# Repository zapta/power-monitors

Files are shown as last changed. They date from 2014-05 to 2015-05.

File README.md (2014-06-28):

POWER PLAY
==========

POWER PLAY are Arduino based smart power monitors that are used to measure and optimize the power consumption of battery operated devices such as smart phones. 

Following is a description of the POWER PLAY models.

POWER PLAY 3.8V
---------------
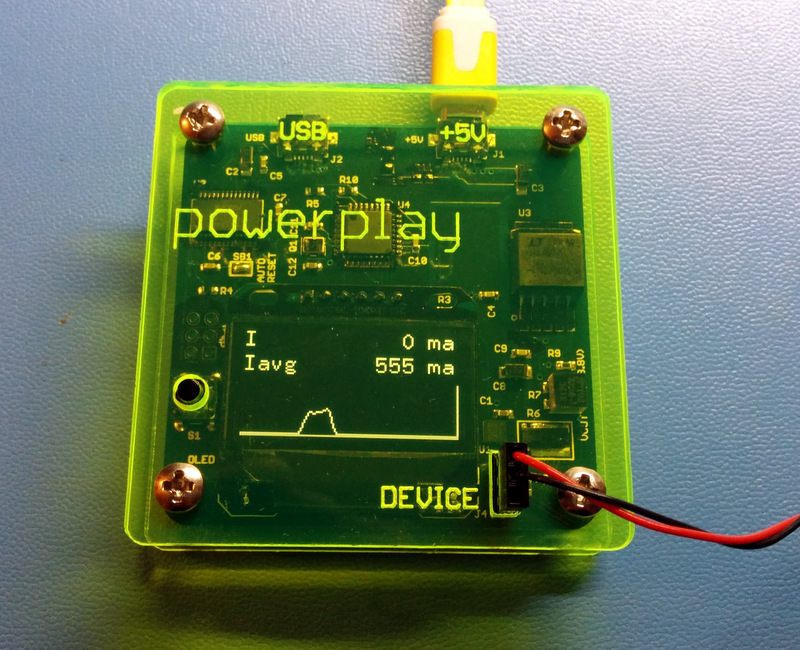
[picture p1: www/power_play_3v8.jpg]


This model provides the most accurate results but requires modifying the tested device. The POWER PLAY 3.8V outputs regulated 3.8 volts are simulates the power provided by a single cell Li-Ion battery cell. It requires disconnecting the battery from the tested device and hooking the output of the POWER PLAY 3.8V instead.

This model has 1.3" OLED display and on board analysis firmware such that it can be operated standalone. In addition is has a FTDI/USB output port that can be used to log the raw data on an attached computer and use it latter for additional analysis.

POWER PLAY 3.8V
---------------
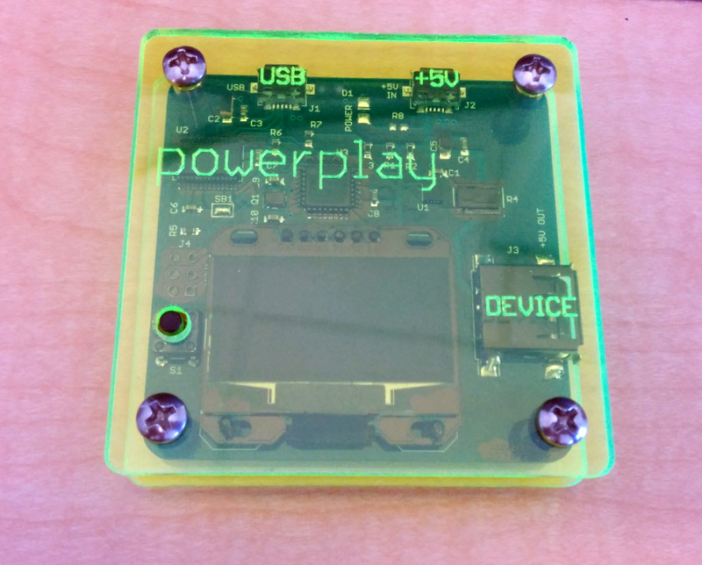
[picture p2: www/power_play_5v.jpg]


This model is identical to the POWER PLAY 3.8V except that it does not have the 3.8V regulator and instead it outputs a pass through 5V. It is intended to be used with unmodified test device by connecting the power to the charger input of the test device and measuring the current fluctuations after the internal battery is fully charged. This method provides less accurate results than the POWER PLAY 3.8V (with the battery removed) but is easier to use since it does not require modifying the test devices.

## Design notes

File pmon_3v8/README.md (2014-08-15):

POWER PLAY 3.8V
===============

## OVERVIEW
POWER PLAY 3V8 is an Arduino based measurement tool that is used to measure the power consumption of mobile devices under different conditions and software versions. It provides 3.8V 2A DC power that simulates a single cell Li-ion battery and is connected to the device **instead of the battery**. The POWER PLAY 3V8 analyzes the current pattern consumed by the device and provides aggregated data on an integral a 1.3" OLED display. It also output the data to a USB/Serial port so it can be logged by a computer for further analysis. The computer based logging is optional and in most cases not consumed since the POWER PLAY 3V8 provides the key results on the display in real time (e.g. the average current consumption over the measurement period).

**WARNING using the POWER PLAY 3.8V required modified devices with batteries removed. This modification should be done by qualified persons only due to the risk of fire, personal injury and even death. The POWER PLAY 3V8 information is provided here as-is and you must consult a qualified person before using it in any way. NEVER operate the POWER PLAY 3V8 with the battery connected to the device under test.**

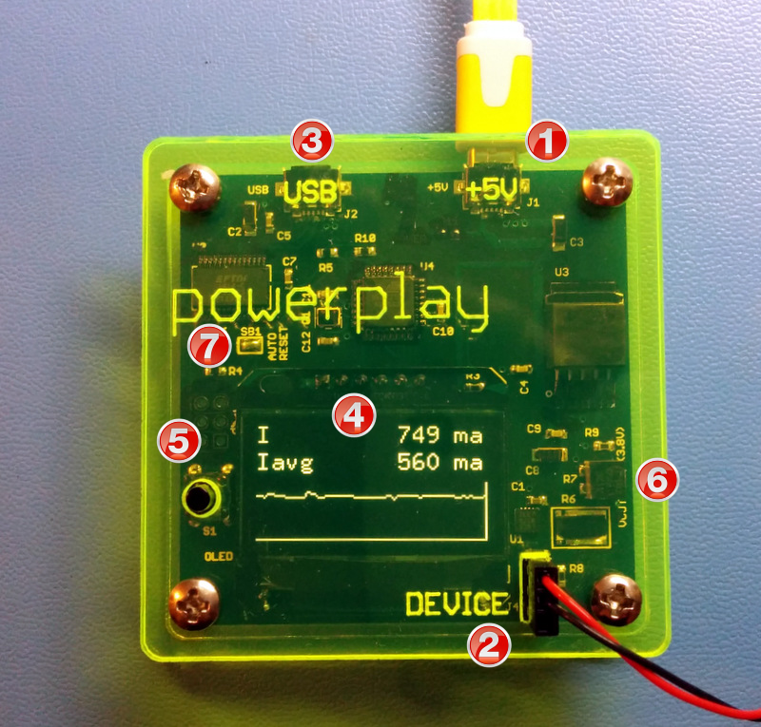
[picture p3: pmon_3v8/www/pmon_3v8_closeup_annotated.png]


1. +5V power input micro USB connector. This connector should be connected to a standard 5V charger and is used to power the POWER PLAY 3V8 and the device under test. It is important to use a charger that can provide sufficient current even during peak current consumption by the device under test. When testing a typical smart phone, powering the POWER PLAY 3V8 from a USB port or a small 1A charger typically result in insufficient current and unstable operation.

2. Power output connection to the device. This is a 3 pin standard servo connector (JR and Hitec style) with ground at the center pin and 3.8V DC (typical) at the two end pins (it's sufficient to use only one of them). This output voltage is adjustable (see below) and is connected to the device instead of the battery, emulating a single cell Lithium-ion battery.

3. USB connector. Using this connector is optional. It allows to log the raw data on an attached computer for later analysis. This connector implements a FTDI serial over USB port and can be access as a serial port on standard Mac OSX, Linux and Windows computers without additional drivers. The emulated serial port is 115.2kbs, 8 data bit, no parity and the data is in ASCII text format.

4. Display. This is a 1.3" monochrome OLED display that shows the analysis results. The display supports multiple pages with different data items.

5. Operation button. A short click switch the displayed data page and a long press (~4 seconds) resets the analysis variables and starts a new analysis session. Holding this button pressed while powering the POWER PLAY 3V8 activates the test screen (for post manufacturing tests).

6. This is a multi turn trim potentiometer that allows to adjust the output voltage in the range 3.6V - 4.2V. It is accessible from the side of the POWER PLAY 3V8 and requires a small flat screwdriver.

7. Auto Reset. This is a solder jumper on the PCB that controls the the USB auto reset feature. When shorted, establishing a new connection via the USB connector resets the POWER PLAY 3V8. This is useful when developing firmware for the POWER PLAY 3V8 using the Arduino IDE. If the auto reset is not desired (e.g. in order to have analysis sessions non interrupted by connecting the USB port), the short should be disconnected with a solder iron (after removing the 4 top screws and top cover).

TODO: add an overall picture with annotation for connectors, display, button and trim pot.

## FUNCTIONAL BLOCK DIAGRAM

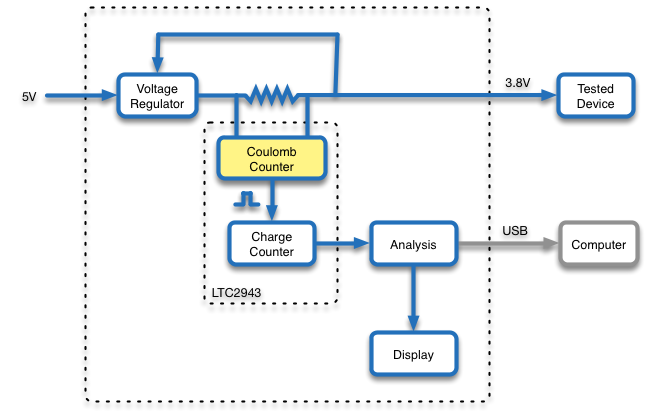
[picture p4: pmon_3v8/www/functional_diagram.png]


* **Voltage regulator** - a 5V to 3.8v low dropout (LDO) voltage regulator. The output voltage (nominal 3.8V) can be set by the small multi turn potentiometer on the right hand of the device.
* **Shunt resistor** - this is a small (25 milliohms) 1% Kelvin resistor that is used to sample the current consumed the the device. The voltage drop on the shunt does not affect the output voltage of the POWER PLAY 3V8 because of the feedback loop between the output voltage and the LDO.
* **Coulomb counter** - this is an analog circuit that continuously integrate the current through the shunt resistor and generates a pulse ('tick') whenever the charge since the last tick reaches a predefined value. (charge is the integral of current over time and is measured in Ampere Hours). For more information read the LTC2943 datasheet at http://www.linear.com/product/LTC2943.
* **Charge counter** - this is a digital counter that counts the Coulomb counter ticks. It provides the long term current integration.
* **Analysis** - this is firmware that tracks the current patterns and computes real time summary data such as momentary current, accumulated charge, number of times device transitioned from standby to wake mode and so on.
* **Display** - a small 1.3" OLED display that display the analysis results. The display has several pages, each with different data items, that can be switched using the button.
* **Computer** - this is an optional computer that logs the data over a USB connection. In most cases, the results displayed on the OLED displayed are sufficient and the computer is not necessary. 

## CONNECTION DIAGRAM

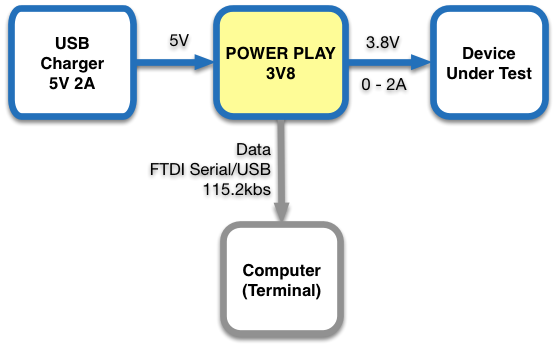
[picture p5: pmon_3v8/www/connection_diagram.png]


Plug the +5V micro usb connector to a USB charger with sufficient current (e.g. 2A). Plug the modified device to the DEVICE connector. Optional: to log the data on a computer connect the USB port to a computer and run a logging program or script (the POWER PLAY 3V8 looks like a 115.2kbs FTDI serial over USB port).

## ANALYSIS

The POWER PLAY 3V8 performs the analysis by dividing the time into slots of 100ms each (10Hz). For each time slot the analysis firmware samples the number of charge ticks occurred in that time slot (partial ticks are rolled to the next time slots, avoiding integration errors) and tracks the total ticks and time in global analysis counters. These counters are reset when the analysis is reset by long pressing the button. These values are used to compute, report and display the following values among others:

* Charge in last time slot.
* Average current during last time slot.
* Last time slot classification (I < ~80ma ? 'standby' : 'wake').
* Total analysis time.
* Total analysis charge (AmpHour).
* Average current during the analysis period.
* Total times of 'wake' and 'standby' slots.
* Total charge in 'wake' and 'standby' slots.
* Number of transitions from a 'standby' to 'wake' time slot.

The most important value from the above list is the average current during the analysis since it is inversely proportional to the expected battery life (for a given battery capacity).

Note: the analysis also samples and reports the momentary voltage level at each slot but in general it assumes that the voltage is fixed and thus does not track power (Watt) or energy (Watt Hour).

## OPERATION

Operating the POWER PLAY 3V8 is very simple. Connect the POWER PLAY 3V8 to a 5V 2A charger and the device under test as described above, reset the analysis by long pressing the button (~4 seconds) and let the device operate under the desired conditions. The analysis is done is real time and the results are shown on the display. Click the button to switch between display pages to see the desired values. 

IMPORTANT: the charger must be able to provide the peak current of the device under test. Make sure to have a brand name charger with sufficient power capabilities (e.g. 2A or larger). If the charger cannot provides the peak current, the device will turn off occasionally. 

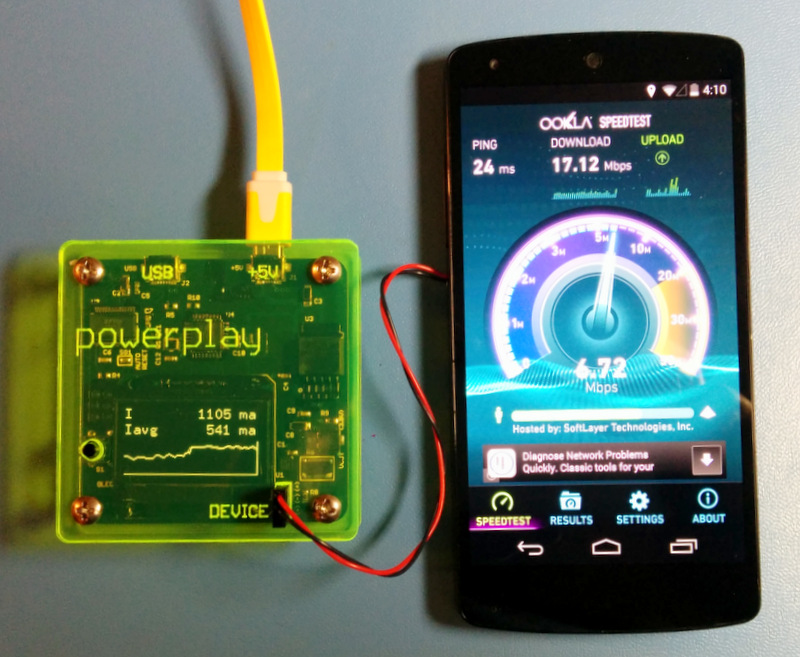
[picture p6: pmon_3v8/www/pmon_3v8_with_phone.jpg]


## LOG FORMAT
POWER PLAY output raw data for logging and offline analysis via the USB port. When connecting to a Linux, Mac OSC or Windows 
computer, the POWER PLAY appears as a serial port without having to install any special driver (it uses the default FTDI driver).
The serial port parameters are 115,200 bps, 8 data bit, no parity and it provides text based data (with CR/LF line ending)
with one record every 100 milliseconds. Each record contains the values listed below with a single space separator between
them.

```
8.200 0.131 0.000 0.163 0 8200 1 1
8.300 0.155 0.000 0.163 0 8300 1 1
8.400 0.131 0.000 0.163 0 8400 1 1
8.500 0.042 0.000 0.161 100 8400 1 0
8.600 0.018 0.000 0.159 200 8400 1 0
8.700 0.018 0.000 0.158 300 8400 1 0
8.800 0.012 0.000 0.156 400 8400 1 0
8.900 0.018 0.000 0.155 500 8400 1 0
9.000 0.030 0.000 0.153 600 8400 1 0
9.100 0.060 0.000 0.152 600 8500 2 1
9.200 0.042 0.000 0.151 700 8500 2 0
```

The fields of each log line are as follows

* **T** - Timestamp since the beginning of the analysis (long press the button) in milliseconds.
* **I** - Average current during the last 100ms time slot, in Amperes.
* **Q** - Total charge since the beginning of the analysis in Ampere/Hours.
* **Iavg** - Average current since the beginning of the analysis in millliamps.
* **Ts** - Total time since the beginning of the analysis of 100ms time slot that were classified as 'standby' (average current was lower than a predefined threshold.
* **Tw** - Total time since the beginning of the analysis of 100ms time slot that were classified as 'wake' (average current was higher than a predefined threshold. (this field is redundant since it is always equals T - Ts).
* **Nw** - number of transitions from a 'standby' (100ms) time slot to a 'wake' time slot. 
* **W** - a boolean flag that indicates if the last 100ms time slot was classified as 'wake' (value = 1) or as 'standby' (value = 0).

## INSTRUMENTING A DEVICE
The process of instrumenting a mobile device to be used with POWER PLAY 3.8V varies for each device and should be done only by qualified personal that understand the device and the hazards of dealing with rechargeable Li-Ion batteries (risk or fire, personal injury and death so **beware**). For that reason, it is in out of the scope of this document.

Following are the steps used to instrument one specific phone model (Nexus 5) that was used to test the POWER PLAY 3.8V. This is provided as general information only and not as a comprehensive guide. The procedure for other devices can be very different, some may require additional capacitors in parallel to the two wires, other can require special 'fake' batteries while others can be completely incompatible with POWER PLAY 3.8V.

1. Open the back cover (pry around)
2. Remove the black plastic cover above the battery (require removal of 6 small screws).
3. Carefully disconnect the battery connector and the large flex connector next to it.
4. Remove the battery (you need to pry below it, be careful not to damage the battery).
5. Place back the large flex cable.
6. Solder two wires to the points shown the in the picture below.
7. Put back the black cover and secure with the 6 screws.
8. Cut a small notch at the edge of the back cover to have clearance for the two wires.
9. Put back the black cover.
10. Solder the two wires to a 3 position HiTech/JR (but not Futaba) servo connector. Connect the center position to the (-) wires and one of the end positions to the (+) wire.

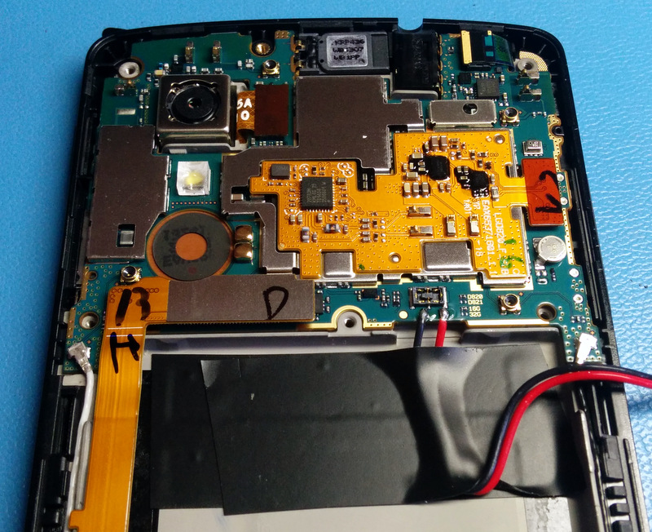
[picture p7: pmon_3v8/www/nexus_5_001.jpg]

The Nexus 5 with cover and battery removed and two wires soldered.

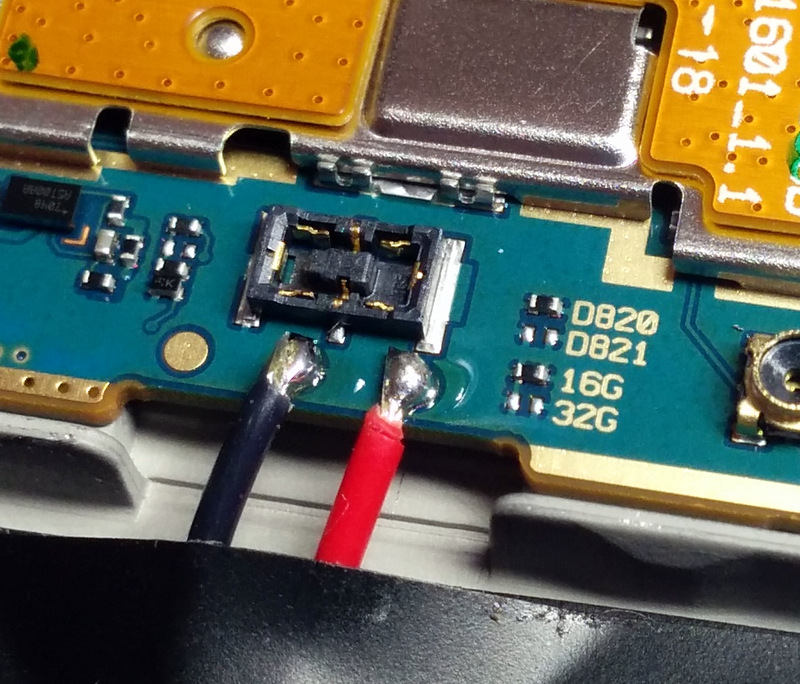
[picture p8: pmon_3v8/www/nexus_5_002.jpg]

A close up of the two connection points.

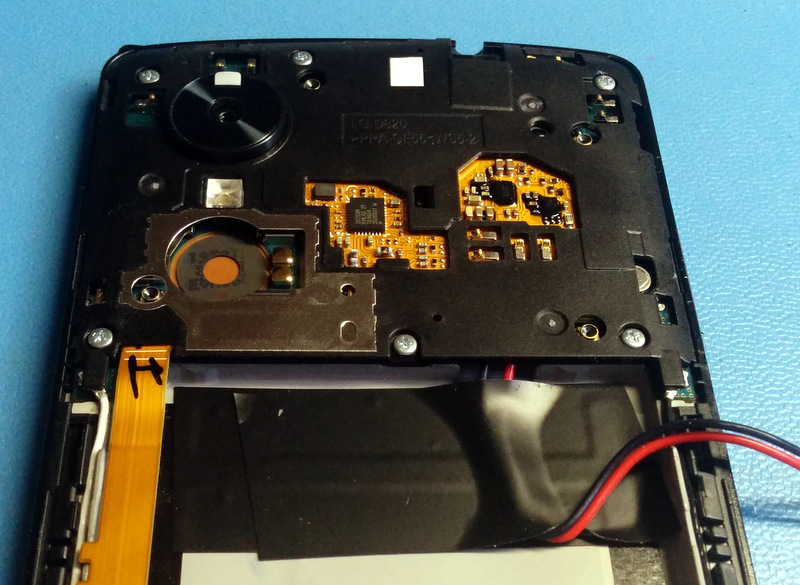
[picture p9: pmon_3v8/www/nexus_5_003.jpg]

The phone with the black cover back in place and the wires secured with tape.

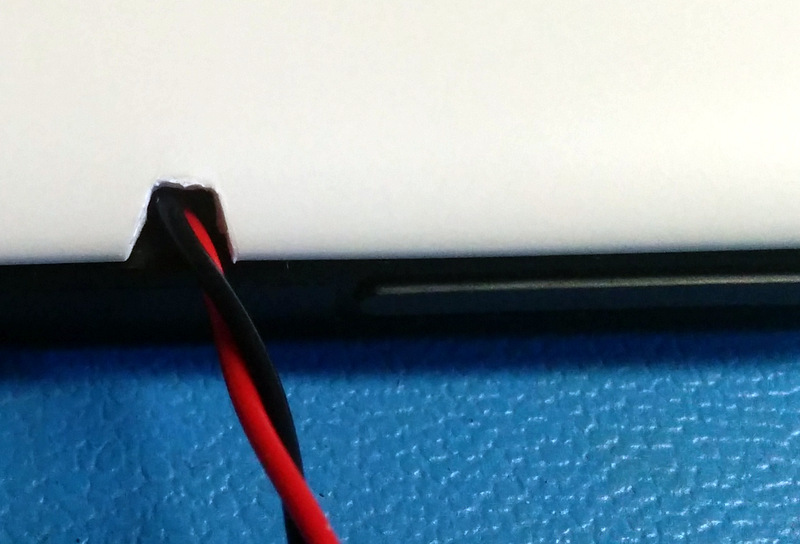
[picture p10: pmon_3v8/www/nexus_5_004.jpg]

The exit point of the two wires.

## FIRMWARE DEVELOPMENT

POWER PLAY 3.8V is compatible with the Arduino IDE and its firmware is an Arduino sketch whose source code is available in this directory. Here are a few notes that will help you setup the development environment.

* You need to power the POWER PLAY 3.8V via its +5V connector in addition to connecting the USB port to the host computer with the Arduino IDE.
* The POWER PLAY 3.8V looks to the Arduino IDE as an Arduino Pro Mini 16Mhz 5V ATMEGA328 board. You need to select it in the Tool section of the IDE menu.
* You can use the IDE serial monitor facility to view output from the POWER PLAY 3.8V.
* The POWER PLAY 3.8V sketch uses the U8glib graphic library. You need to install it on your Arduino IDE before being to compile the POWER PLAY 3.8V sketch. To do so, follow the 'manual instructions' here https://code.google.com/p/u8glib/wiki/u8glib (using the IDE's library import function results in compilation errors).

## BUILDING POWER PLAY 3V8

Follow these steps to build your own POWER PLAY: 

* Purchase the electronic components listed in the Bill Of Material (BOM) file. Most components are available from common sources such as digikey.com. You can purchase the OLED display directly from heltec.cn or from retailers such as eBay sellers. Make sure to purchase a white SPI display with 6 pins that match the pins in the schema (these display use the SSD1306 controller).
* Order the printed circuit board (PCB). It is a 2 layers PCB with a Sick of Beige 60mm x 60mm form factor. Some vendors such as OSHPark.com accept Eagle .brd files directly. Others such as elecrow.com require you to generate gerber files using their custom Eagle .cam files.
* Order a SMD stencil (5mil or 0.125mm) for the PCB. For best results, use a metal stencil (e.g. from elecrow.com) rather than mylar.
(optional) Make the top and bottom laser cut covers. We got the best results with acrylic 1/8” fluoro blue or green. If you do not have access to a laser cutter, you can order online from services such as ponoko.com. 
* Print, pick-and-place and reflow the SMD components, including the two micro USB connectors (use solder paste, the stencil and the reflow method of your choice such as hot air station, hot plate or a toaster oven).
* Solder the through-hole components (two 1 pin OLED support posts, OLED display, push button, and 3 pin output header). Connecting the solder jumper SB1 is optional but recommended.
* Power the board via the +5V connector and use an ICSP programmer of your choice (e.g. Atmel ICSP MKII with pogo pins) to program the MCU  (see the script file icsp_program_all.sh for an example). Alternatively, you can program the MCU before soldering, using a universal programmer. This step programs the MCU fuses, the MCU Arduino bootloader, and the POWER PLAY firmware. 
* (optional) Assemble the top and bottom covers using the screws and spacers listed in the BOM. If not using the covers, you can use screws and nuts to have the PCB standing on 4 legs.

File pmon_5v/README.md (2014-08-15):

POWER PLAY 5V
=============

## OVERVIEW
POWER PLAY 5V is identical to the POWER PLAY 3.8V except that it passes through the input 5V instead of down regulating it to 3.8V. This allows to use unmodified test devices (that is, no need to remove the battery) and the cost of slightly less accurate results do the quiescent current of the internal charger circuitry of the test devices and potential difference is software behavior due to the detection of the charger power. 

Since many aspects of POWER PLAY 5V are identical to POWER PLAY 3.8V, we list here only the differences.

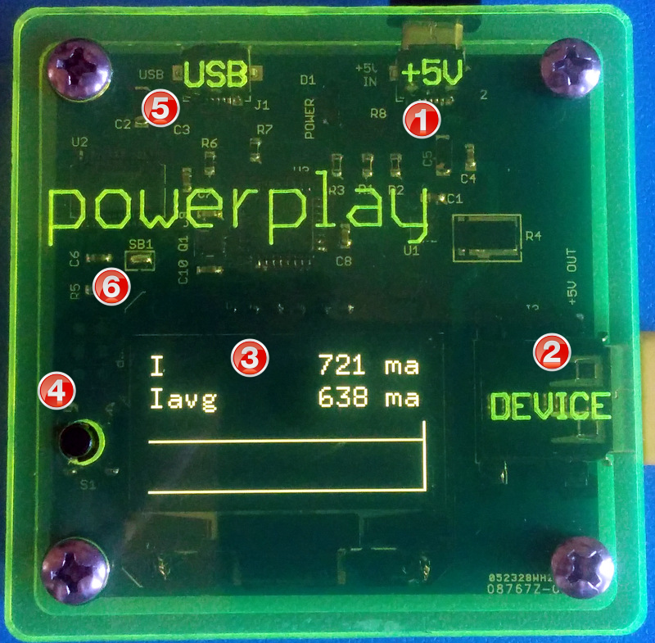
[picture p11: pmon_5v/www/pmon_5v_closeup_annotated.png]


1. +5V power input micro USB connector. Identical to POWER PLAY 3.8V.

2. Power output connection to the device. Connect this using a short USB cable to the test device.

3. Display. Identical to POWER PLAY 3.8V.

4. Operation button. Identical to POWER PLAY 3.8V.

5. USB connector. Identical to POWER PLAY 3.8V.

6. Auto Reset solder jumper. Identical to POWER PLAY 3.8V.

## FUNCTIONAL BLOCK DIAGRAM

Identical to POWER PLAY 3.8V except that a pass through wire replaces the 3.8V regulator.

## CONNECTION DIAGRAM

Identical to POWER PLAY 3.8V except that the test device is powered via its USB charger port.

## ANALYSIS

Identical to POWER PLAY 3.8V.

## OPERATION

1. Connect the +5V connector to 2A or larger charger.
2. Connect the DEVICE connector to the charger port of the test device (e.g. Nexus 5).
3. Wait until the device is *fully* charged.
4. Long press the button to reset the analysis and let POWER PLAY monitor the current for some time.
5. Note the Iavg value. This is the baseline current consumption of your device.
6. Install the new app and repeat steps 4, 5. The difference in Iavg values with and without the app indicates the power consumption of the app (lower is better).
7. Optimize the app and repeat. Your users will love you for better battery life.

## LOG FORMAT

Identical to POWER PLAY 3.8V.

## INSTRUMENTING A DEVICE

Not required.

## FIRMWARE DEVELOPMENT

Identical to POWER PLAY 3.8V.

## BUILDING POWER PLAY 5V. 

Similar to POWER PLAY 3.8V.

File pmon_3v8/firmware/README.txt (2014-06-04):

Arduino PMon OLED board programming.

Use AVR ICSP programmer such as AVR ISP MKII and programming software
such as AVRDUDE or AVRDUDES. Many other programmers and programming
software will also work.

Use the 2x3 ICSP programming header on the Pmon OLED board. Make sure you
orient it correctly (connect from the top side, pay attention to pin 1).
You can solder header pins or use pogo pins like Sparkfun's 
ISP Pogo Adapter. Other adapters like Hobbyking's Atmega Socket Firmware 
Flashing Tool may also work.

MCU type: ATmeta328P

Fuses:
L  : 0xFF
H  : 0xDA
E  : 0x05
LB : 0x3F

Flash image: pmon_oled_flash.hex

The image includes an Arduino Mini Pro bootloader so once
programmed, you can program software changes directly from
the Arduino IDE (board = Arduino Pro Mini 5V 16Mhz) via the 
USB port.

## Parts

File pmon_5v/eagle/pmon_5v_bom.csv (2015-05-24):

Quantity | Digi-Key Part Number | Description | Package | Manufacturer Name | Manufacturer Part Number | Part Numbers | Comments
1 | FC4L64R025FERCT-ND | 0.025 ohm 1% 2W Kelvin | SMT 2512 | Ohmite | FC4L64R025FER | R4
4 | 311-3.30KHRCT-ND | 3.3K 5% 1/10W | SMT 0603 | Yageo | RC0603FR-073K3L | R1 R2 R3 R8 | Generic part
3 | 311-10KGRCT-ND | 10k 5% 1/10W | SMT 0603 | Yageo | RC0603JR-0710KL | R5 R6 R7 | Generic part
2 | 311-1424-1-ND | 20pF 50V 5% | SMT 0603 | Yageo | CC0603JRNPO9BN200 | C9 C10 | Generic part
5 | 311-1344-1-ND | 0.1uf 10% 25V | SMT 0603 | Yageo | CC0603KRX7R9BB104 | C3 C5 C6 C7 C8 | Generic part. May need to reduce C7 if interferes with ICSP reset (e.g. to 0.01)
3 | 445-1604-1-ND | 1uF 16V 5% | SMT 6030 | TDK Corporation | C1608X7R1C105K080AC | C1 C11 C12 | Generic part
2 | 399-3684-1-ND | 10uF 10% 16V | SMT 1206 | Kemet | T491A106K010AT | C2 C4 | Generic part
1 | CTX732CT-ND | 16Mhz Crystal 20pf | 4-SMD 3.20mm x 2.50mm | CTS-Frequency Control | 403C11E16M00000 | Q1 | CTS 403 Series 20pF.
1 | ATMEGA328P-AURCT-ND | ATMEGA328P | TQFP32 | Atmel | ATMEGA328P-AUR | U3 | Atmel AVR328P
1 | 768-1007-1-ND | FT232RL | SSOP28 | FTDI | FT232RL-REEL | U2
1 | LTC2943CDD#PBF-ND | LTC2943 | DFN8 | Liner Technology | LTC2943CDD#PBF | U1 | Adjustable LDO 3A.
1 | TC10154.0VCT713CT-ND | TC1015 | SOT23-5 | Microchip Technology | TC1015-4.0VCT713 | U4 | Fixed LDO 4.0V.
1 | P12197S-ND | Push button |  | Panasonic Electronic Components | EVQ-PAG09K | S1 | Panasonic EVQ-PAG09K
2 | S1011E-36-ND | 1 position 0.1" straight |  | Sullins Connector Solutions | PBC36SAAN | OLED mechanical support. | Generic part. Height above board should be at most 8.5mm. The part number here is for a 36 position breakable strip so it can be used for multiple boards.
2 | H11611CT-ND | Micro USB 'reversed' connector |  | Hirose Electric Co Ltd | ZX62RD-AB-5P8 | J1 J2 | Hirose ZX62RD-AB-5P8. Make sure it is a 'reversed' connector otherwise the signals will be in reversed order.
1 | WM7087TR-ND | USB A connector |  | Molex Inc | 482580002 | J3 | Molex 48258-0002
4 | 335-1156-ND | M3x6mm pan head philips machine screw |  | APM Hexseal | RM3X6MM 2701 |  | Top cover screws
4 | 335-1148-ND | M3x10mm pan head philips machine screw |  | APM Hexseal | RM3X10MM 2701 |  | Bottom cover screws
4 | 952-1515-ND | M3x6mm round threaded female/female metal standoff |  | Harwin | R30-5000602 |  | Top cover standoff
4 | 952-1526-ND | M3x3mm round non threaded nylon or metal spacer |  | Harwin | R30-6700394 |  | Bottom cover spacer
1 | N/A | Heltec 1.3" SPI 128X64 OLED WHITE monochrome display with RST pin. |  | Heltec |  | OLED | Must have SSD1306 controller and these 6 pins: GND VCC SCL SDA RST D/C (picture here http://i.imgur.com/y3cWazS.jpg). Manufacturer is http://www.heltec.cn. Heltec also similar blue models (with sh1063 controller) and 'new' models with different 6 pins (VCC and GND swapped no RST pin) these two models are incompatible with the current POWER PLAY design.
1 | N/A | PCB |  |  |  |  | Order the PCB from your favorite PCB manufacturer (2 layers 60x60mm). Make sure to order a SMD stencil preferably 5mil stainless steal but even a 5 mil stencil from oshstencils.com should work.
1 | N/A | Top cover |  |  |  |  | Laser cut fluorescent green 1/8" acryilic.
1 | N/A | Bottom Cover |  |  |  |  | Laser cut fluorescent green 1/8" acryilic.

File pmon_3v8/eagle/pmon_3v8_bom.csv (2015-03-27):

Quantity | Description | Part Designators | Digikey Part Number | Comments
1 | 0.025 ohm 1% Kelvin | R6 | FC4L64R025FERCT-ND | Ohmite FC4L64R025FER
5 | 3.3K 1% 1/10W 0603 | R1 R2 R3 R9 R11 | P3.30KHCT-ND
1 | 8.2K 1% 1/10W 0603 | R8 | P8.20KHCT-ND
3 | 10k 5% 1/10W 0603 | R4 R5 R10 | 311-10KGRCT-ND
1 | 1K 12 turns side adjustment | R7 | 3224J-102ECT-ND | Bourns 3224J-1-102E
2 | 20pF 50V 5% 0603 | C11 C12 | 311-1424-1-ND
6 | 0.1uf 10% 25V 0603 | C4 C5 C6 C7 C9 C10 | 311-1344-1-ND | Reduce C7 if interferes with ICSP reset (e.g. to 0.01)
3 | Ceramic cap 1uF 16V 5% 0603 | C1 C13 C14 | 445-1604-1-ND
3 | Tantalum cap 10uF 10% 16V 1206 | C2 C3 C8 | 399-3684-1-ND
1 | Heltec 1.3" SPI 128X64 OLED WHITE monochrome display with RST pin. | OLED |  | http://www.heltec.diytrade.com or http://r.ebay.com/bVQ2CYMust have SSD1306 controller and these 6 pins: GND VCC SCL SDA RST D/C (picture here http://i.imgur.com/y3cWazS.jpg). Manufacturer is http://www.heltec.cn. Heltec also similar blue models (with sh1063 controller) and 'new' models with different 6 pins (VCC and GND swapped no RST pin) these two models are incompatible with the current POWER PLAY design.
1 | 16Mhz crystal | Q1 | CTX732CT-ND | CTS 403 Series 20pF.
1 | ATMEGA328P TQFP32 | U4 | ATMEGA328P-AURCT-ND | Atmel AVR328P
1 | FT232RL SSOP28 | U2 | 768-1007-1-ND
1 | LTC2943 DFN8 | U1 | LTC2943CDD#PBF-ND
1 | LT1764AEQ TO263 | U3 | LT1764AEQ#TRPBFCT-ND | Adjustable LDO 3A.
1 | TC1015 SOT23-5 | U5 | TC10154.0VCT713CT-ND | Fixed LDO 4.0V.
1 | Push button | S1 | P12197S-ND | Panasonic EVQ-PAG09K
1 | 3 positions 0.1" header straight | J4 | S1011E-36-ND | Generic part. Height above board should be at most 8.5mm. The part number here is for a 36 position breakable strip so it can be used for multiple boards.
2 | 1 position 0.1" header straight | OLED mechanical support. | S1011E-36-ND | Generic part. Height above board should be at most 8.5mm. The part number here is for a 36 position breakable strip so it can be used for multiple boards.
1 | RC Hitech/JR servo 3 positions male connector + 2 pins | Mates with J3 |  | Any RC store or ebay. The top cover laser cut was design for JR/Hitech housings not Futaba.
2 | Micro USB 'reversed' connector | J1 J2 | H11611CT-ND | Hirose ZX62RD-AB-5P8. Make sure it is a 'reversed' connector otherwise the signals will be in reversed order.
1 | PCB |  |  | Order the PCB from your favorite PCB manufacturer (2 layers 60x60mm). Make sure to order a SMD stencil preferably 5mil stainless steal but even a 5 mil stencil from oshstencils.com should work.
1 | Top cover custom acrylic |  |  | Laser cut fluorescent green 1/8" acryilic.
1 | Bottom cover custom acrylic |  |  | Laser cut fluorescent green 1/8" acryilic.
4 | M3x6mm pan head philips machine screw |  | 335-1156-ND | Top cover screws
4 | M3x10mm pan head philips machine screw |  | 335-1148-ND | Bottom cover screws
4 | M3x6mm round threaded female/female metal standoff |  | 952-1515-ND | Top cover standoff
4 | M3x3mm round non threaded nylon or metal spacer |  | 952-1526-ND | Bottom cover spacer

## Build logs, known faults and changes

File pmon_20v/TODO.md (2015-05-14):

TODO list for The Arduino PMON UNO

**SCHEMATIC**
* Add solder jumpers for OLED soft configuration.

**LAYOUT**
* Add to the OLED footprint a tplace rectangle with the active display area.
* Add to the OLED footprint a restrict/keepout for the area below the passive components.

** Enclosure

**SOFTWARE**

**MISCELLANEOUS**
* Add README.md file

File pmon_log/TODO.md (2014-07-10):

TODO list for The Arduino PMON UNO

**SCHEMATIC**

**LAYOUT**

** Enclosure

**SOFTWARE**

**MISCELLANEOUS**

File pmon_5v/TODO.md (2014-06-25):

TODO list for The Arduino PMON UNO

**SCHEMATIC**
* Add solder jumpers for OLED soft configuration.
* Add a 10K resistor from OLED RST to ground to have smoother startup.

**LAYOUT**
* Add to the OLED footprint a tplace rectangle with the active display area.
* Add to the OLED footprint a restrict/keepout for the area below the passive components.
* Add BOM

** Enclosure

**SOFTWARE**
* Show time as [[hh:]mm:]ss.

**MISCELLANEOUS**

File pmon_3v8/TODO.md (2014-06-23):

TODO list for POWER PLAY 3V8

**SCHEMATIC**
* Find part number of a button without the fifth ground pin.
* Add config pin for new OLED configuraiton.

**LAYOUT**
* Add to the OLED footprint a tplace rectangle with the active display area.
* Add to the OLED footprint a restrict/keepout for the area below the passive components.
* Add to top silkscreen layer display dignal names.

** Enclosure

**SOFTWARE**
* Make sure zero current is mapped in the graph to bottom display row.

**MISCELLANEOUS**

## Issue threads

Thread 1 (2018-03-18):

error when upload

lutfisan, 2018-03-18:
I use arduino nano,
when I verify the code it is ok, but when I upload it I get error

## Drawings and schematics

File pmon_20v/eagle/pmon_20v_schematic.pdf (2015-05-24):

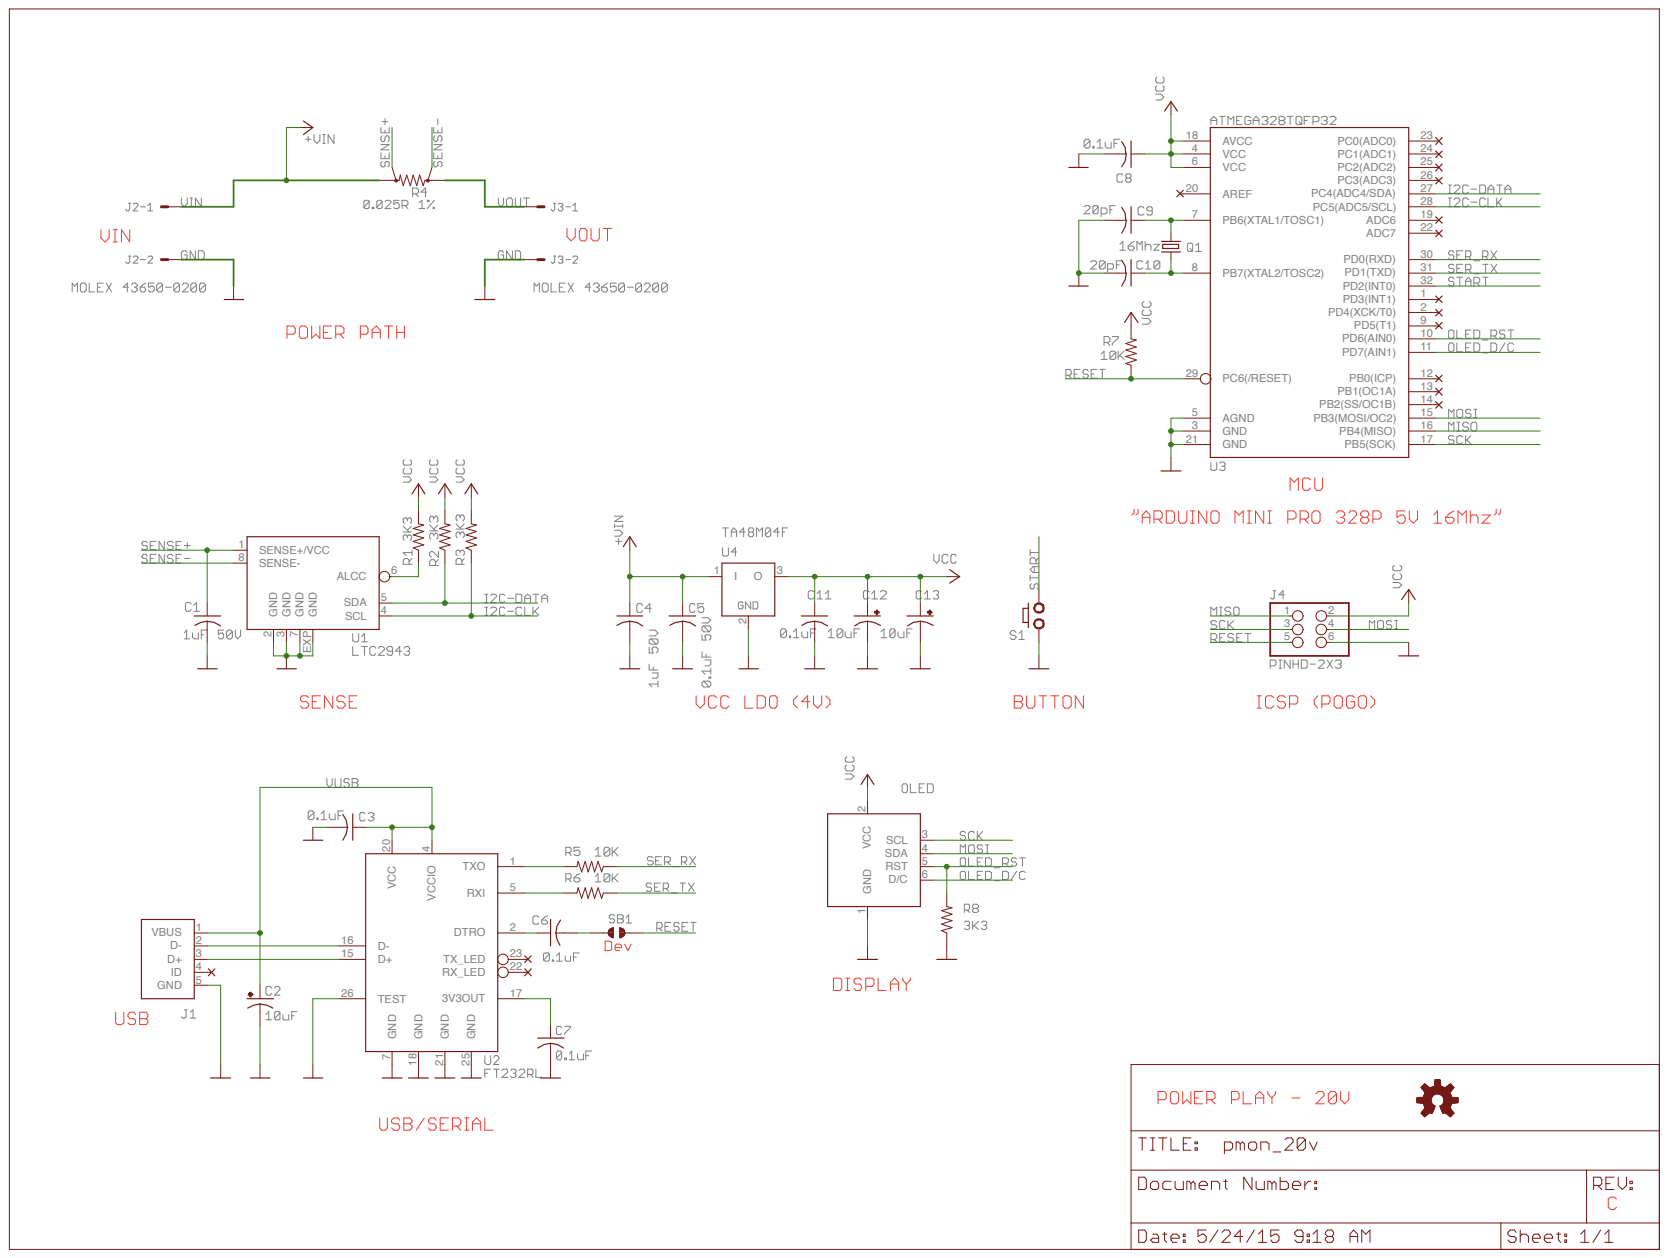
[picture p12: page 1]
ALCC; GND 2; GND 3; GND 7; GND EXP; SCL; 4 SDA; SENSE+/VCC; SENSE-; GND; VBUS; ADC6; ADC7; AGND; AREF 20; AVCC 18; 3 GND 21; PB0(ICP); PB3(MOSI/OC2); PB4(MISO); PB5(SCK); PB6(XTAL1/TOSC1); PB7(XTAL2/TOSC2); PC0(ADC0); PC1(ADC1); PC2(ADC2); PC3(ADC3); PC4(ADC4/SDA); PC5(ADC5/SCL); PC6(/RESET) 29; PD0(RXD); PD1(TXD); PD2(INT0); PD3(INT1); PD4(XCK/T0); PD6(AIN0); PD7(AIN1); VCC; 3V3OUT; DTRO; GND 18; GND 21; GND 25 RXI; RX_LED; TEST 26; TXO; TX_LED; VCC 20; VCCIO 4; GND 1; RST; SDA

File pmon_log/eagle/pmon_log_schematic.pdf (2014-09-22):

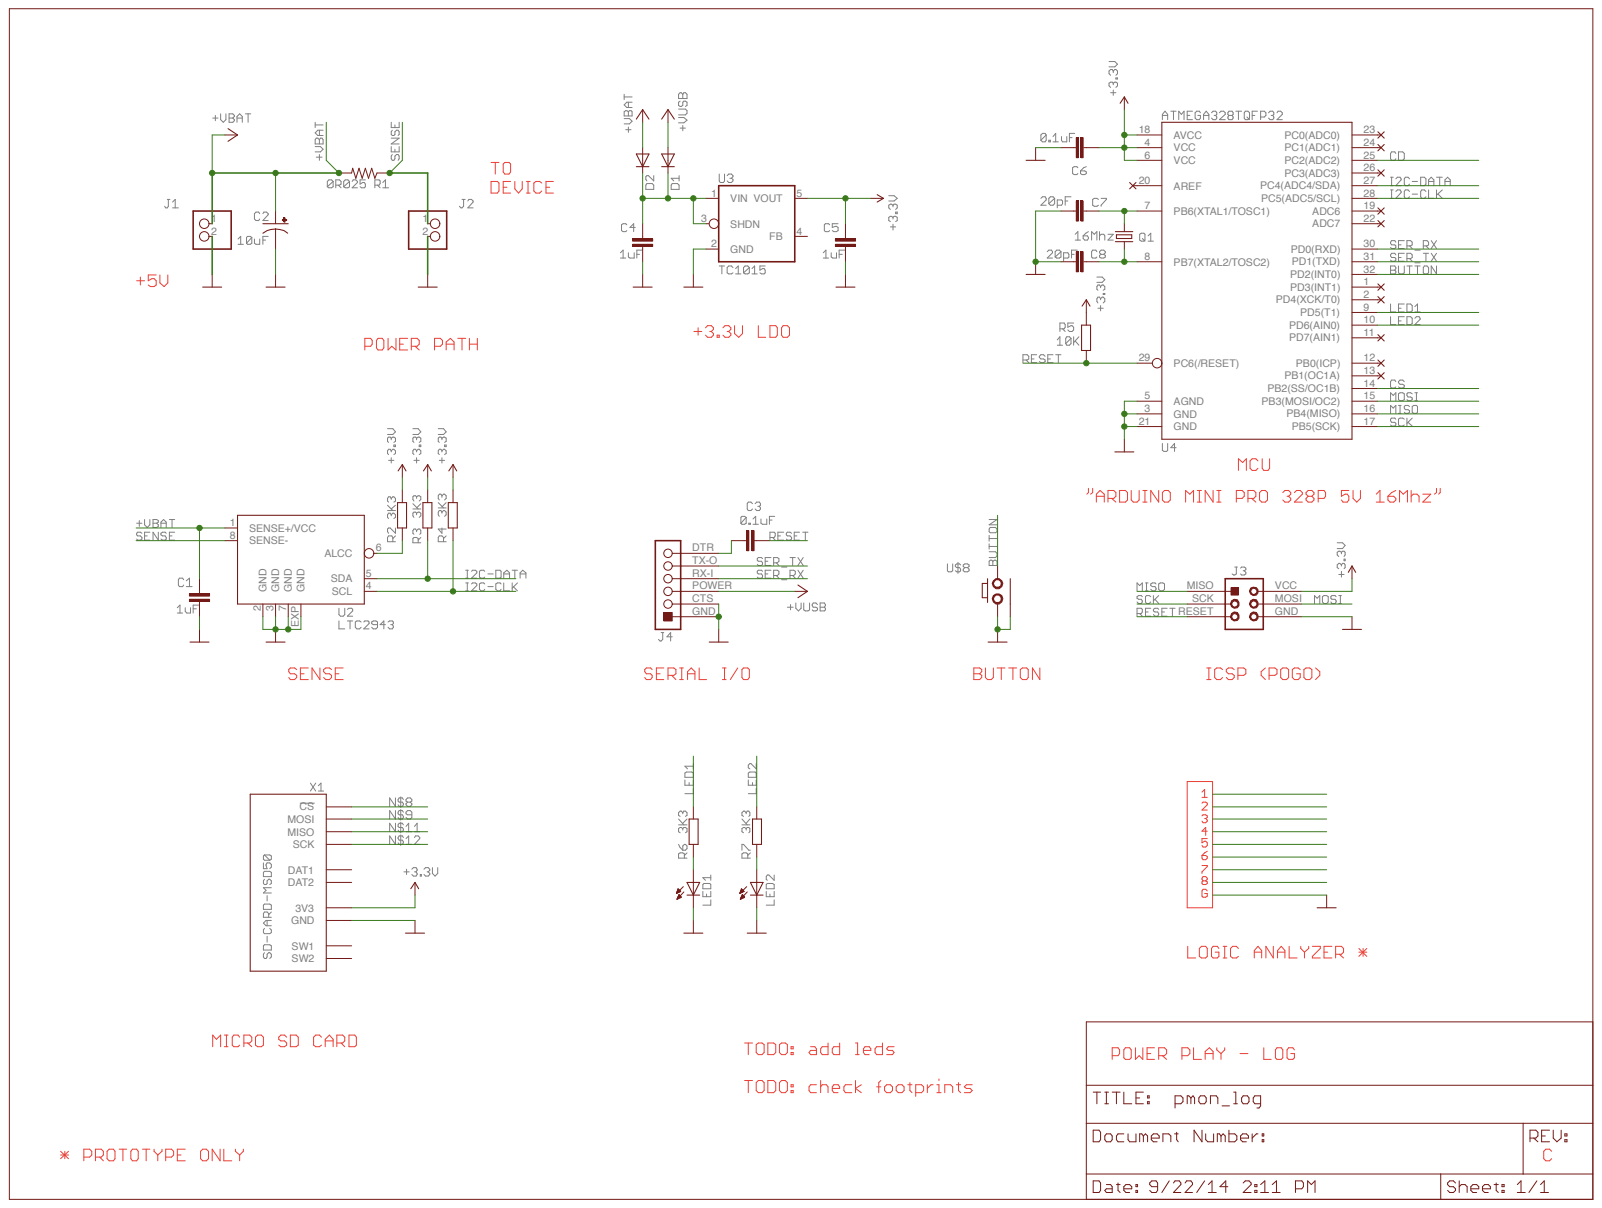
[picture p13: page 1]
ALCC; GND 2; GND 3; GND 7; GND EXP; SCL; 4 SDA; SENSE+/VCC; SENSE-; ADC6; ADC7; AGND; AREF 20; AVCC 18; GND; 3 GND 21; PB0(ICP); PB3(MOSI/OC2); PB4(MISO); PB5(SCK); PB6(XTAL1/TOSC1); PB7(XTAL2/TOSC2); PC0(ADC0); PC1(ADC1); PC2(ADC2); PC3(ADC3); PC4(ADC4/SDA); PC5(ADC5/SCL); PC6(/RESET) 29; PD0(RXD); PD1(TXD); PD2(INT0); PD3(INT1); PD4(XCK/T0); PD6(AIN0); PD7(AIN1); VCC; SHDN; VIN; VOUT; MISO; SCK; MOSI; RESET; CTS; POWER; DTR; DAT1 DAT2

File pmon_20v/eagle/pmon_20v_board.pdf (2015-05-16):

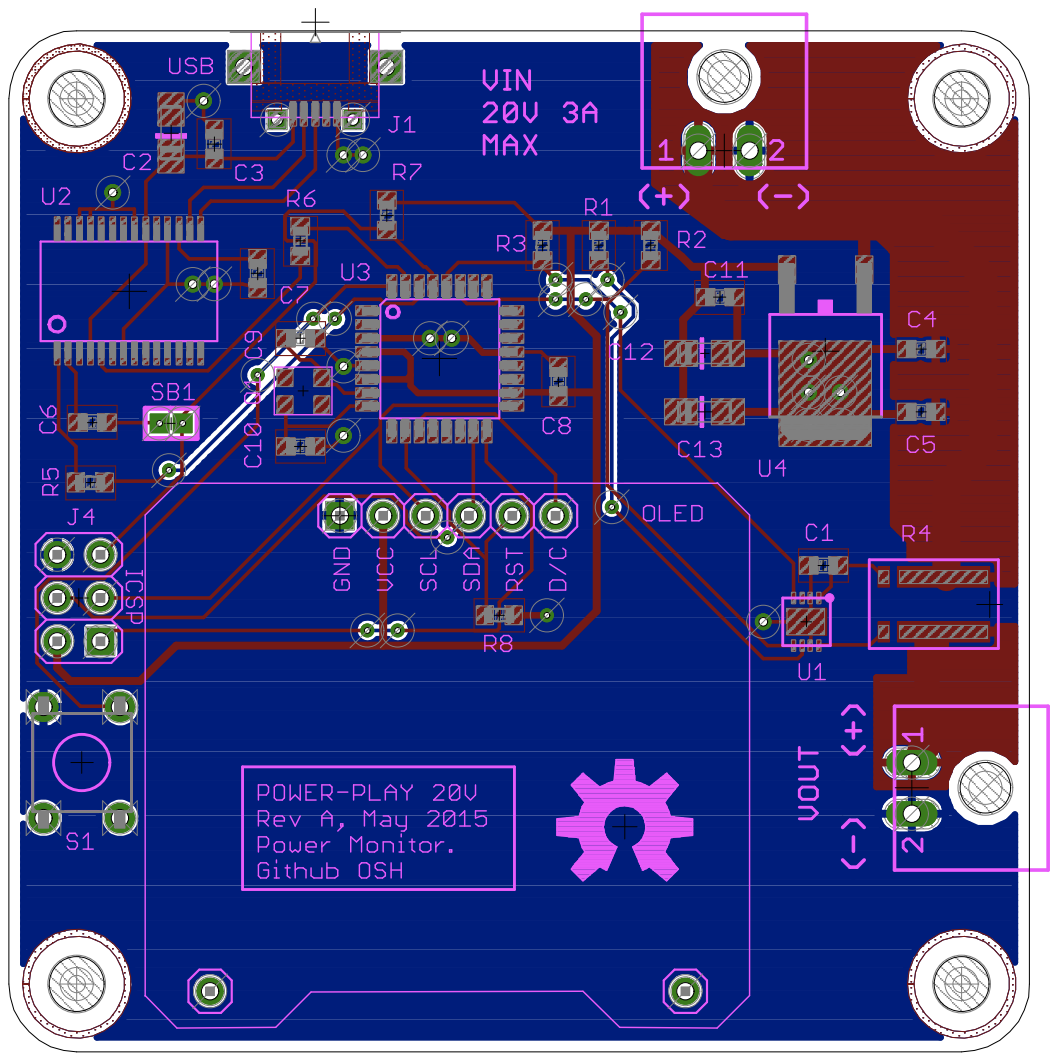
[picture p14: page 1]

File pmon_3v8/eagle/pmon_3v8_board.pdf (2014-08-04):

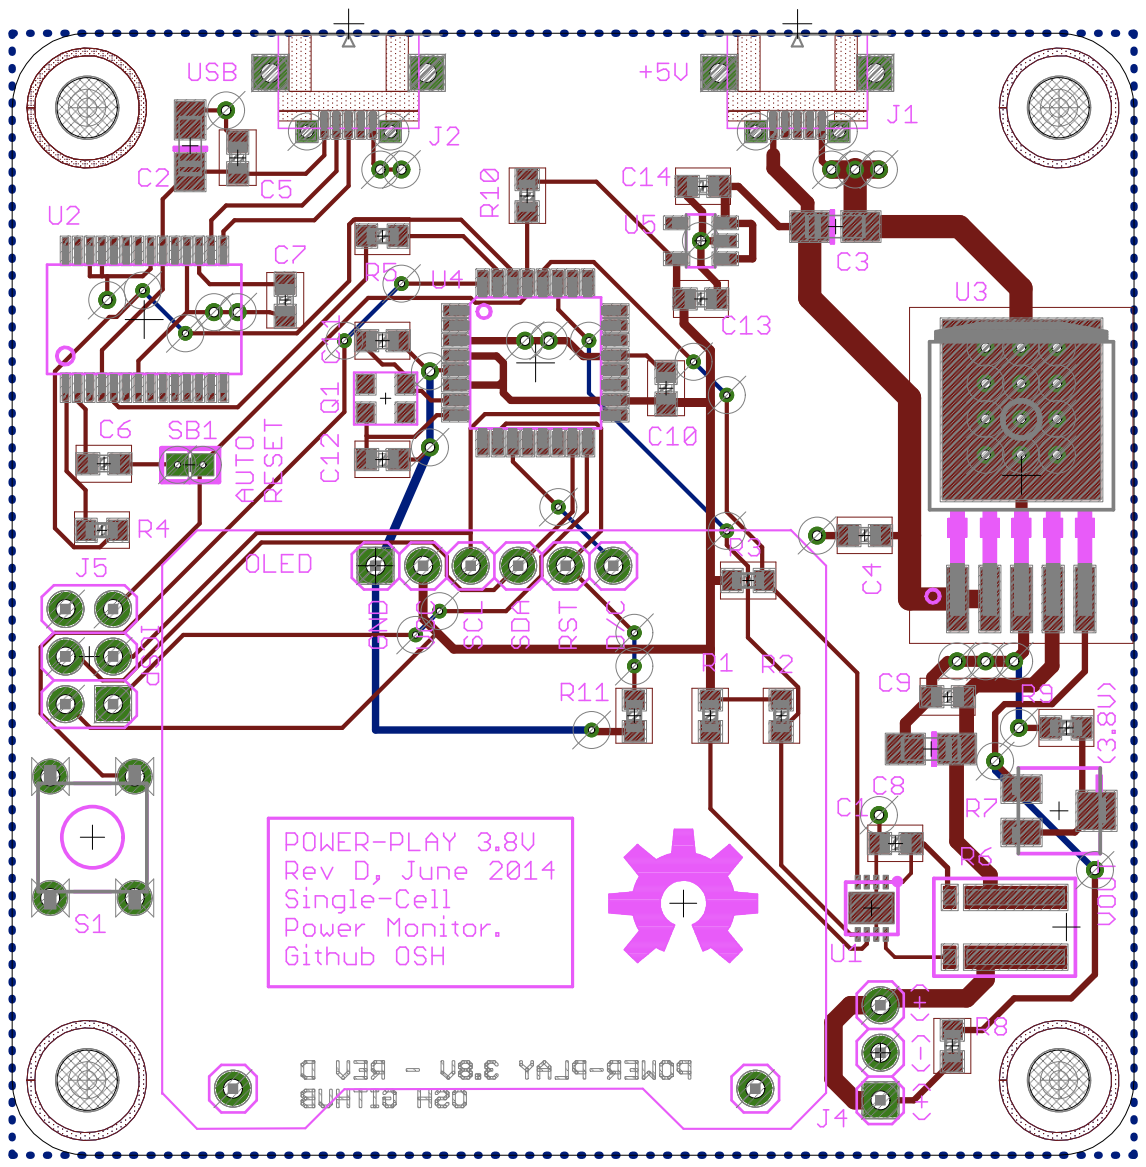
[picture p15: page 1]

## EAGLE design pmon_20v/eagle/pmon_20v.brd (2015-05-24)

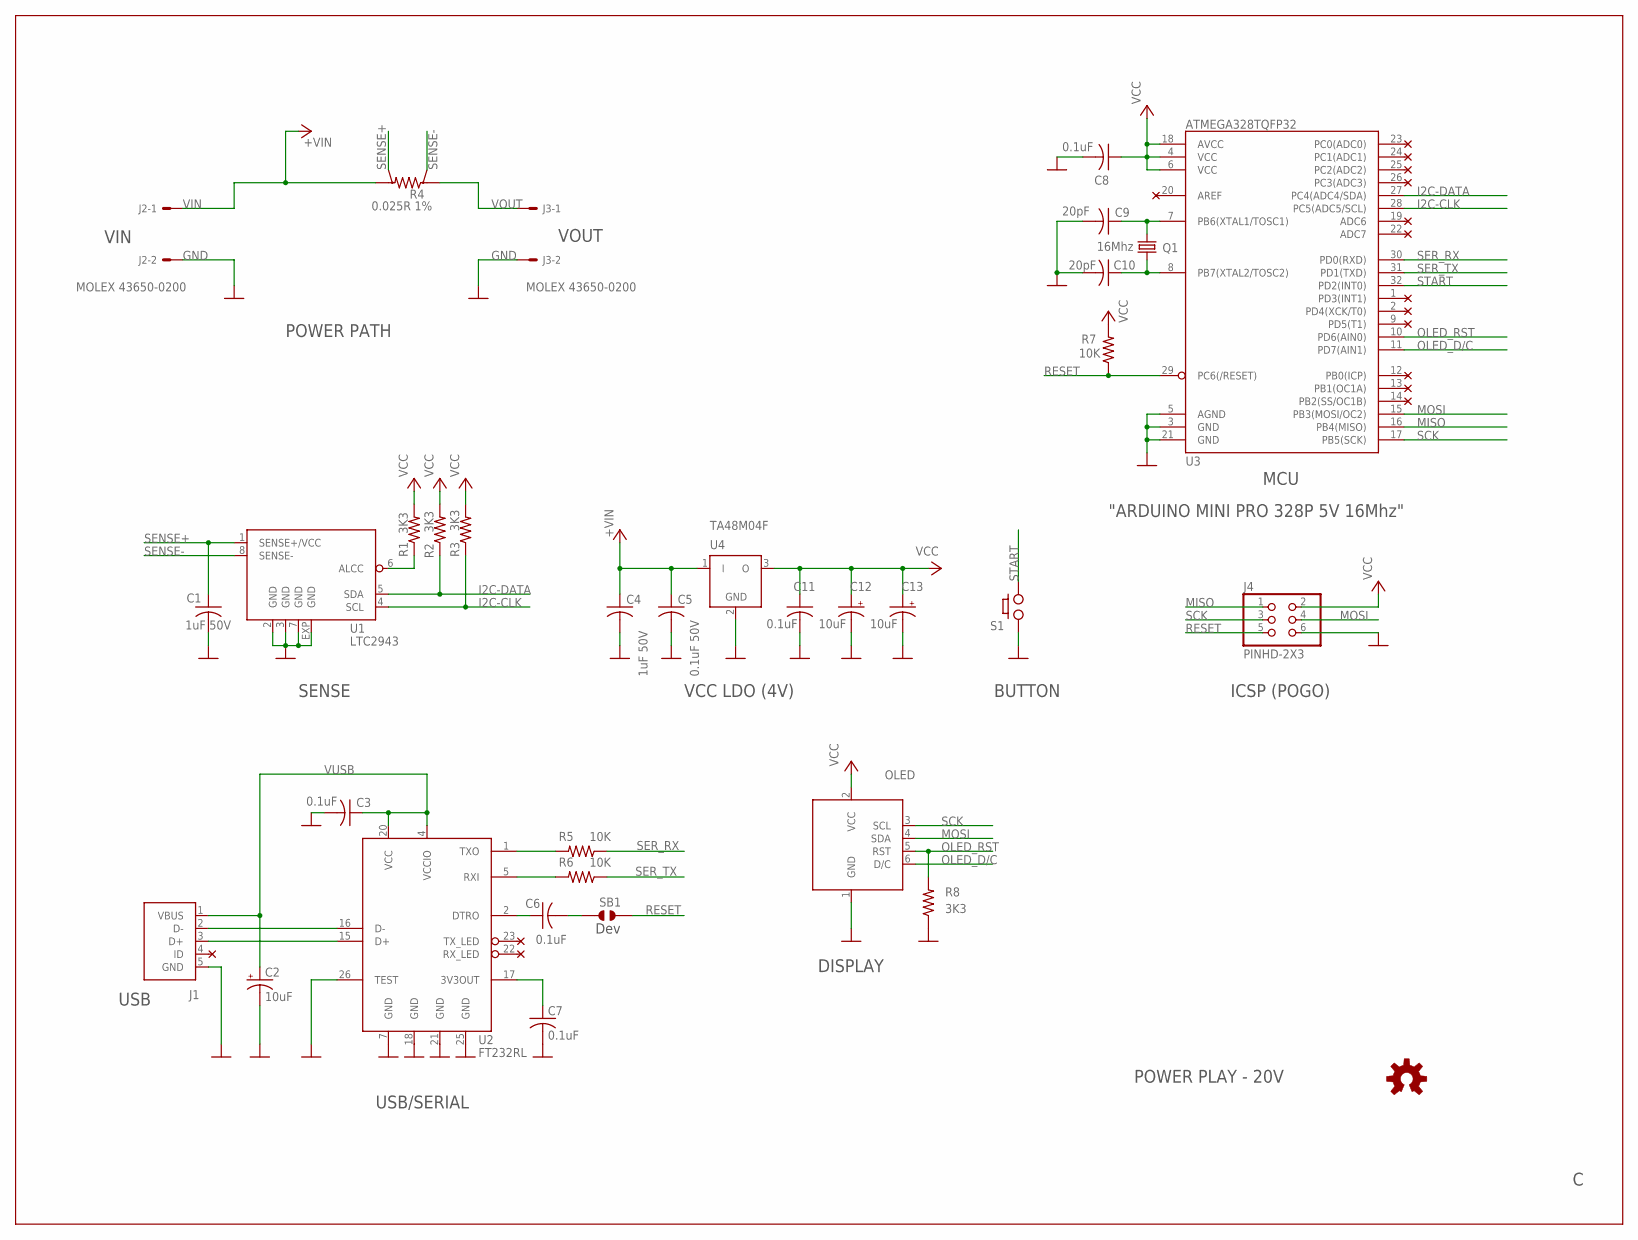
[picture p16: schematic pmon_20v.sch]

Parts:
C1, C4: 1uF 50V; C0603
C2, C12, C13: 10uF; A/3216-18R
C3, C6, C7, C8, C11: 0.1uF; C0603
C5: 0.1uF 50V; C0603
C9, C10: 20pF; C0603
J1: USB; USB-MICRO-ZX62RD-AB-5P8
J2, J3: MOLEX 43650-0200; POWER_CON
J4: PINHD-2X3; 2X03
OLED: OLED
Q1: 16Mhz; CRYSTAL-CTS406
R1, R2, R3, R8: 3K3; R0603
R4: 0.025R 1%; KELVIN-6432
R5, R6, R7: 10K; R0603
S1: PUSH_BUTTON; TLE1105
SB1: JUMPER_SOLDER_1X2
U1: LTC2943; DFN8-3X3
U2: FT232RL; SSOP28DB
U3: ATMEGA328TQFP32; TQFP32-08
U4: TA48M04F; DPACK
U$28: OSH

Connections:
GND: C1.2, C2.-, C3.2, C4.2, C5.2, C7.2, C8.2, C9.2, C10.2, C11.2, C12.-, C13.-, J1.5 (GND), J2.2, J3.2, J4.6, OLED.1 (GND), R8.1, S1.A (1), U1.2 (GND), U1.3 (GND), U1.7 (GND), U1.EXP (GND), U2.7 (GND), U2.18 (GND), U2.21 (GND), U2.25 (GND), U2.26 (TEST), U3.3 (GND), U3.5 (AGND), U3.21 (GND), U4.2 (GND)
I2C-CLK: R3.1, U1.4 (SCL), U3.28 (PC5(ADC5/SCL))
I2C-DATA: R2.1, U1.5 (SDA), U3.27 (PC4(ADC4/SDA))
MISO: J4.1, U3.16 (PB4(MISO))
MOSI: J4.4, OLED.4 (SDA), U3.15 (PB3(MOSI/OC2))
unnamed: R1.1, U1.6 (ALCC)
unnamed: C9.1, Q1.1, U3.7 (PB6(XTAL1/TOSC1))
unnamed: R5.2, U2.1 (TXO)
unnamed: C10.1, Q1.3 (2), U3.8 (PB7(XTAL2/TOSC2))
unnamed: R6.2, U2.5 (RXI)
unnamed: J1.3 (D+), U2.15 (D+)
unnamed: C6.1, U2.2 (DTRO)
unnamed: C6.2, SB1.1
unnamed: J1.2 (D-), U2.16 (D-)
unnamed: C7.1, U2.17 (3V3OUT)
OLED_D/C: OLED.6 (D/C), U3.11 (PD7(AIN1))
OLED_RST: OLED.5 (RST), R8.2, U3.10 (PD6(AIN0))
RESET: J4.5, R7.1, SB1.2, U3.29 (PC6(/RESET))
SCK: J4.3, OLED.3 (SCL), U3.17 (PB5(SCK))
SENSE+: C1.1, R4.V2, U1.1 (SENSE+/VCC)
SENSE-: R4.V1, U1.8 (SENSE-)
SER_RX: R5.1, U3.30 (PD0(RXD))
SER_TX: R6.1, U3.31 (PD1(TXD))
START: S1.B (2), U3.32 (PD2(INT0))
VCC: C8.1, C11.1, C12.+, C13.+, J4.2, OLED.2 (VCC), R1.2, R2.2, R3.2, R7.2, U3.4 (VCC), U3.6 (VCC), U3.18 (AVCC), U4.3 (O)
VIN: C4.1, C5.1, J2.1, R4.I2, U4.1 (I)
VOUT: J3.1, R4.I1
VUSB: C2.+, C3.1, J1.1 (VBUS), U2.4 (VCCIO), U2.20 (VCC)

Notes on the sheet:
USB/SERIAL
ICSP (POGO)
MCU
POWER PLAY - 20V
SENSE
POWER PATH
VIN
USB
VOUT
"ARDUINO MINI PRO 328P 5V 16Mhz"
BUTTON
DISPLAY
Dev
VCC LDO (4V)

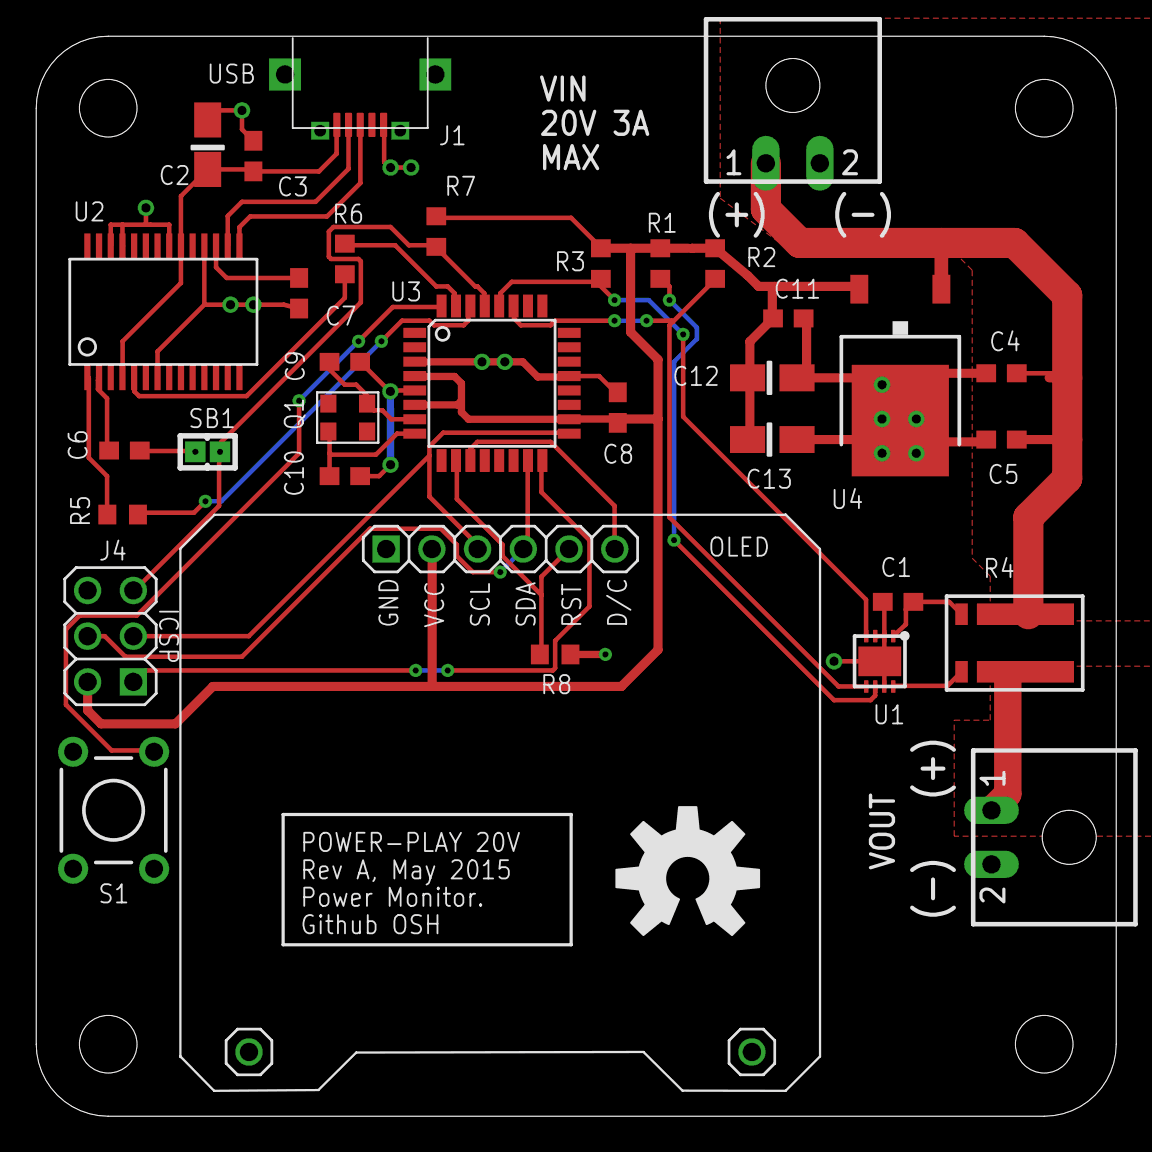
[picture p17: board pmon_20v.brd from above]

Board: 2 copper layers, 60.0 x 60.0 mm, 34 parts (0 on the bottom side), 28 nets.

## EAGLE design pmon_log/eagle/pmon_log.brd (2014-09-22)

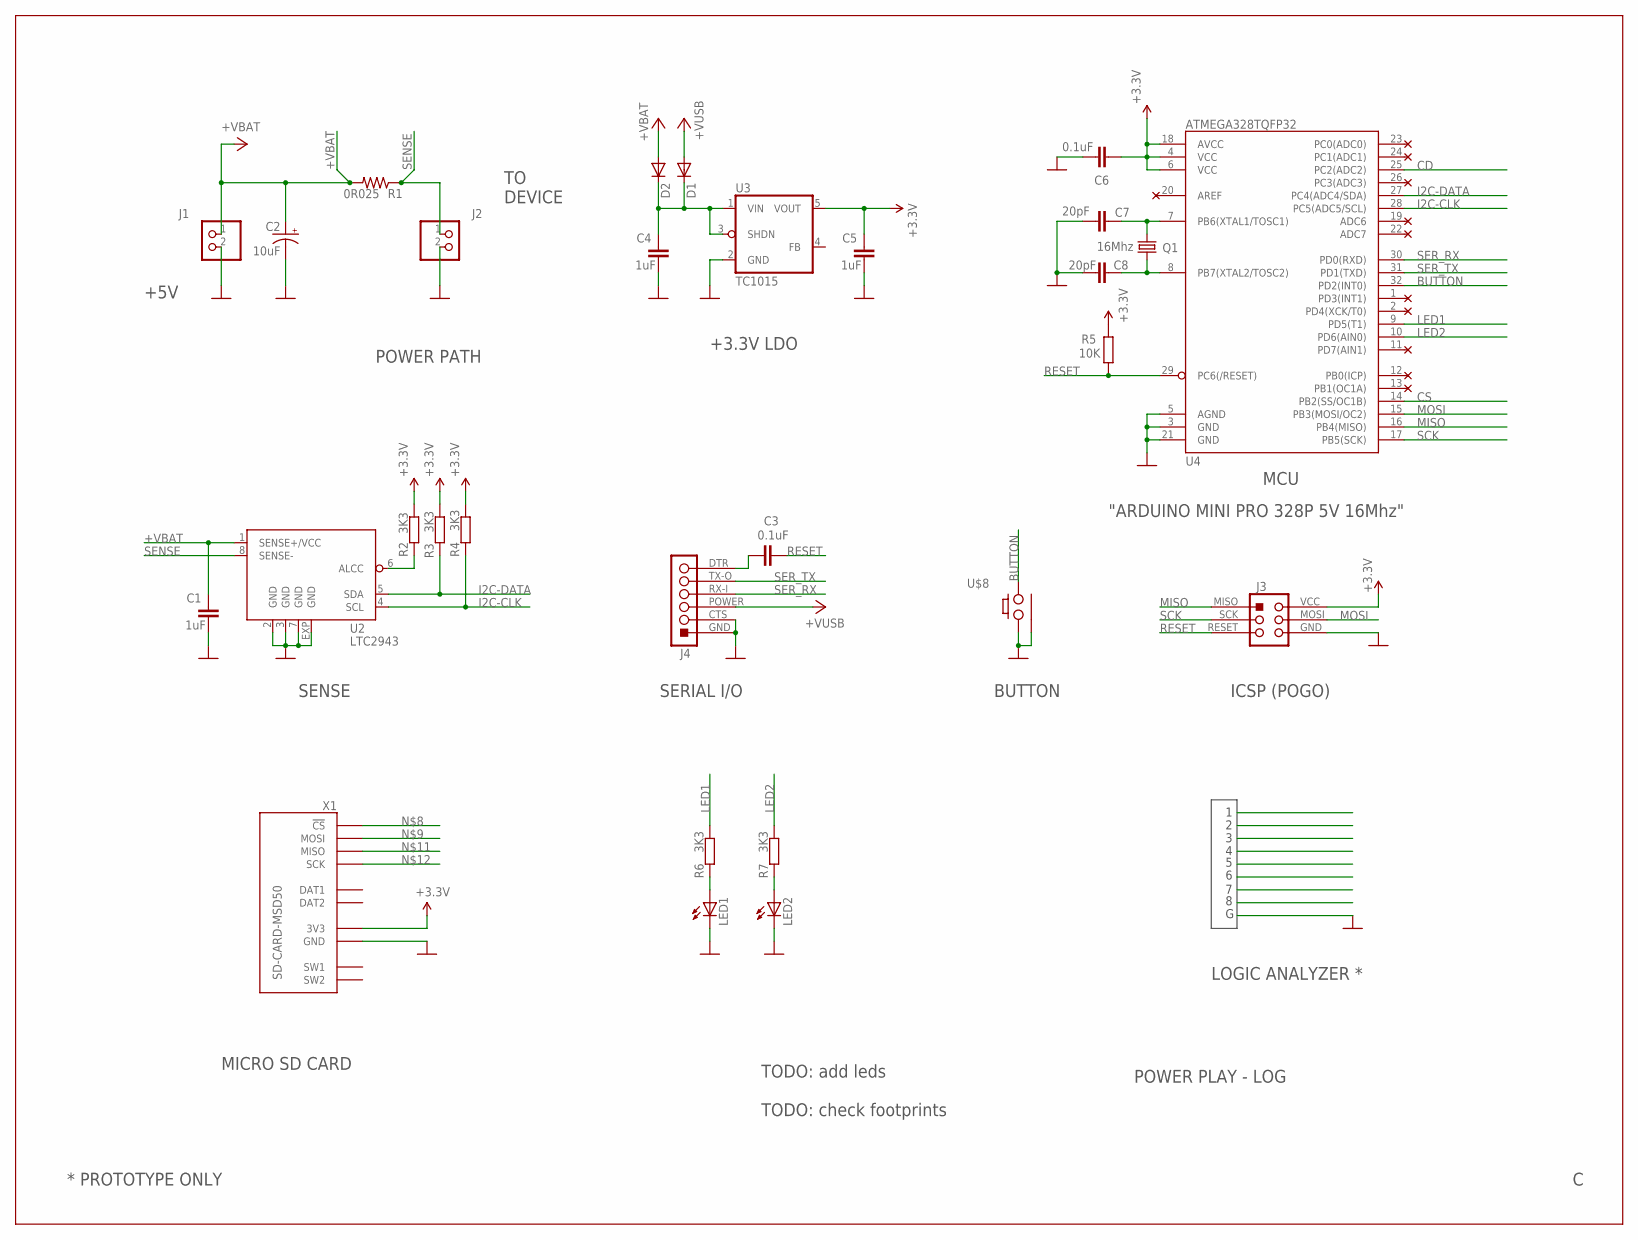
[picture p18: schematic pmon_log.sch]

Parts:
C1, C4, C5: 1uF; C0402K
C2: 10uF; A/3216-18R
C3, C6: 0.1uF; C0402K
C7, C8: 20pF; C0402K
D1, D2: DIODE-SC79_INFINEON; SC79_INFINEON
J1, J2: PINHD-1X2; 1X02
J3: ICSP
J4: SERIAL_HEADER
LED1, LED2: LEDCHIPLED_0603; CHIPLED_0603
Q1: 16Mhz; CRYSTAL-CTS406
R1: 0R025; R0603
R2, R3, R4, R6, R7: 3K3; R0402
R5: 10K; R0402
U2: LTC2943; DFN8-3X3
U3: TC1015; SOT25
U4: ATMEGA328TQFP32; TQFP32-08
U$8: PUSH_BUTTON_GND
X1: SD-CARD-MSD50; SD_5031821853

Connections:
+3.3V: X1.VCC (3V3)
+4V: C5.1, C6.1, J3.VCC, R2.2, R3.2, R4.2, R5.2, U3.5 (VOUT), U4.4 (VCC), U4.6 (VCC), U4.18 (AVCC)
+USB: D1.A, J4.POWER (3)
+VBAT: C1.1, C2.+, D2.A, J1.1, R1.2, U2.1 (SENSE+/VCC)
BUTTON: U4.32 (PD2(INT0)), U$8.HOLE1 (2)
CD: U4.25 (PC2(ADC2))
CS: U4.14 (PB2(SS/OC1B))
GND: C1.2, C2.-, C4.2, C5.2, C6.2, C7.2, C8.2, J1.2, J2.2, J3.GND, J4.CTS (2), J4.GND (1), LED1.C, LED2.C, U2.2 (GND), U2.3 (GND), U2.7 (GND), U2.EXP (GND), U3.2 (GND), U4.3 (GND), U4.5 (AGND), U4.21 (GND), U$8.A1 (1), U$8.GND, X1.GND
I2C-CLK: R4.1, U2.4 (SCL), U4.28 (PC5(ADC5/SCL))
I2C-DATA: R3.1, U2.5 (SDA), U4.27 (PC4(ADC4/SDA))
LED1: R6.2, U4.9 (PD5(T1))
LED2: R7.2, U4.10 (PD6(AIN0))
MISO: J3.MISO, U4.16 (PB4(MISO))
MOSI: J3.MOSI, U4.15 (PB3(MOSI/OC2))
unnamed: R2.1, U2.6 (ALCC)
unnamed: C7.1, Q1.1, U4.7 (PB6(XTAL1/TOSC1))
unnamed: C4.1, D1.C, D2.C, U3.1 (VIN), U3.3 (SHDN)
unnamed: LED1.A, R6.1
unnamed: LED2.A, R7.1
unnamed: C8.1, Q1.3 (2), U4.8 (PB7(XTAL2/TOSC2))
unnamed: C3.2, J4.DTR (6)
RESET: C3.1, J3.RESET, R5.1, U4.29 (PC6(/RESET))
SCK: J3.SCK, U4.17 (PB5(SCK))
SENSE: J2.1, R1.1, U2.8 (SENSE-)
SER_RX: J4.RX-I (4), U4.30 (PD0(RXD))
SER_TX: J4.TX-O (5), U4.31 (PD1(TXD))

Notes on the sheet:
ICSP (POGO)
MCU
POWER PLAY - LOG
SENSE
POWER PATH
+5V
LOGIC ANALYZER *
TO DEVICE
* PROTOTYPE ONLY
"ARDUINO MINI PRO 328P 5V 16Mhz"
BUTTON
+3.3V LDO
TODO: add leds
TODO: check footprints
SERIAL I/O
MICRO SD CARD

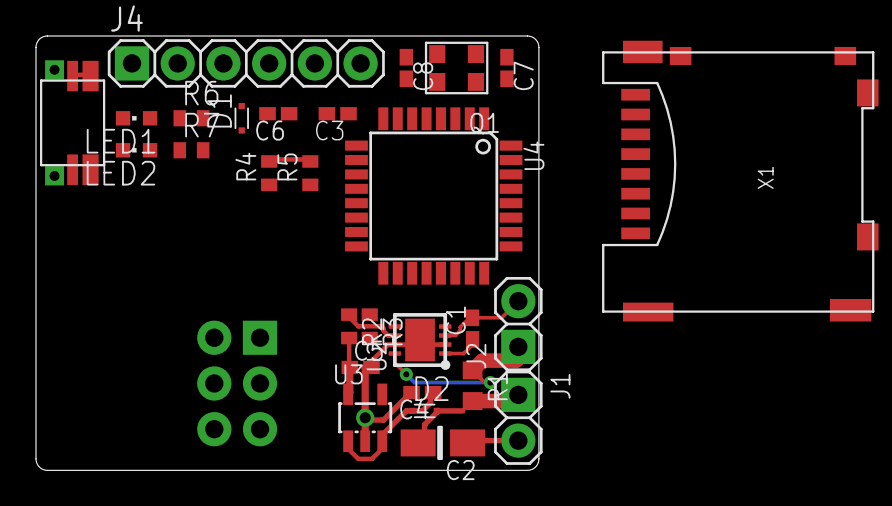
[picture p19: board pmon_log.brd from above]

Board: 2 copper layers, 27.9 x 24.1 mm, 29 parts (1 on the bottom side), 23 nets.

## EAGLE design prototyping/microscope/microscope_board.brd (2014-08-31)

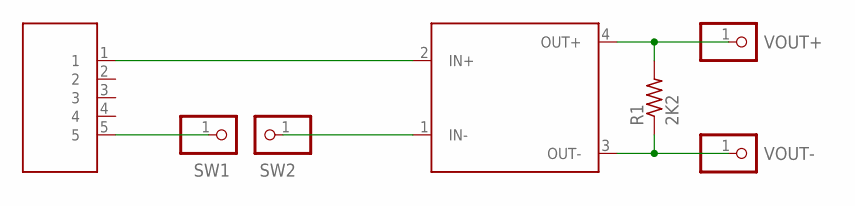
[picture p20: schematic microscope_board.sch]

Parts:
R1: 2K2; R0805
SW1, SW2: PINHD-1X1; 1X01
U$1: DC_DC
U$2: USB_CONNECTOR
VOUT+: PINHD-1X1; 1X01
VOUT-: PINHD-1X1; 1X01

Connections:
unnamed: R1.2, U$1.4 (OUT+), VOUT+.1
unnamed: R1.1, U$1.3 (OUT-), VOUT-.1
unnamed: U$1.2 (IN+), U$2.1
unnamed: SW1.1, U$2.5
unnamed: SW2.1, U$1.1 (IN-)

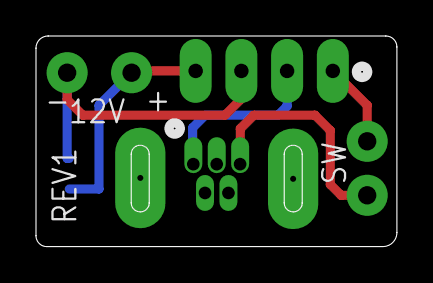
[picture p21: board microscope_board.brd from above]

Board: 2 copper layers, 20.1 x 11.7 mm, 7 parts (1 on the bottom side), 5 nets.

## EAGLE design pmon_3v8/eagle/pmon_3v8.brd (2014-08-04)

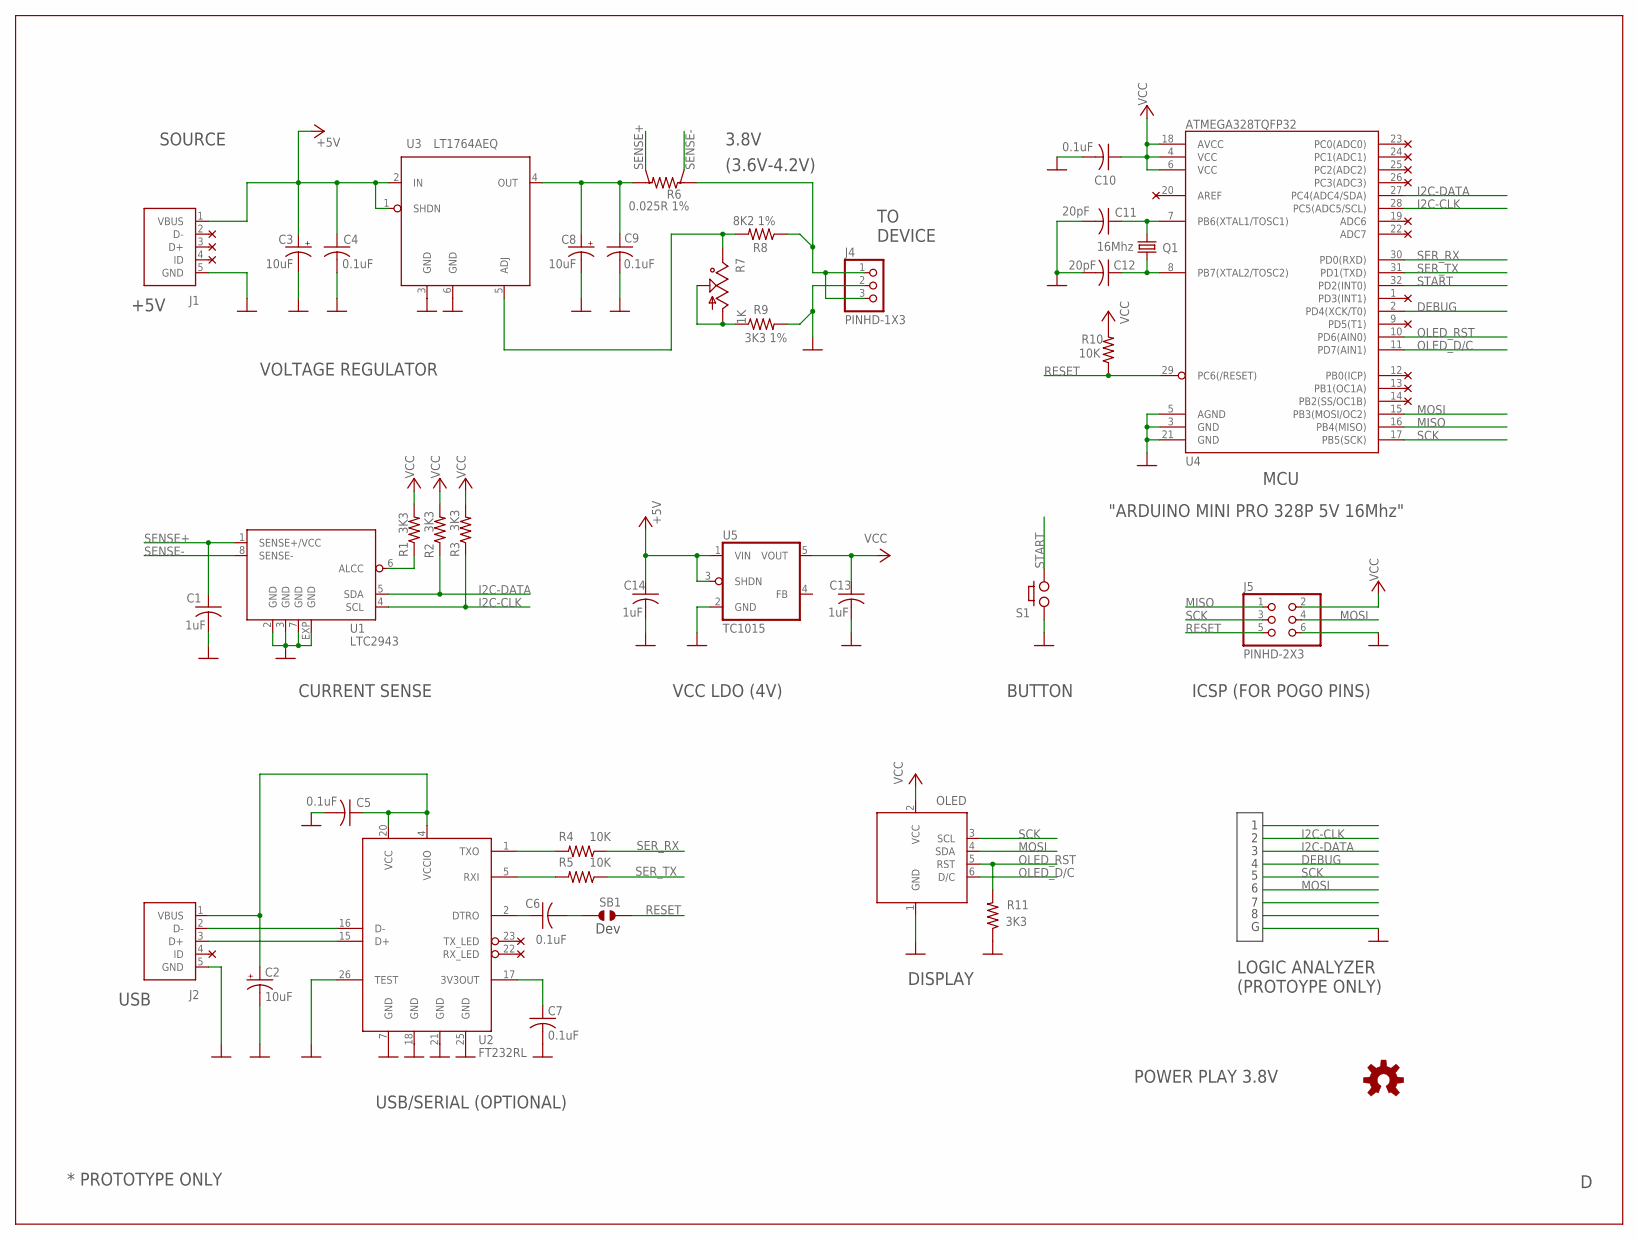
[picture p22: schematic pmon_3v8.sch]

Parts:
C1, C13, C14: 1uF; C0603
C2, C3, C8: 10uF; A/3216-18R
C4, C5, C6, C7, C9, C10: 0.1uF; C0603
C11, C12: 20pF; C0603
J1, J2: USB; USB-MICRO-ZX62RD-AB-5P8
J4: PINHD-1X3; 1X03
J5: PINHD-2X3; 2X03
OLED: OLED
Q1: 16Mhz; CRYSTAL-CTS406
R1, R2, R3, R11: 3K3; R0603
R4, R5, R10: 10K; R0603
R6: 0.025R 1%; KELVIN-6432
R7: 1K; TRIM-POT_SM-42/43A
R8: 8K2 1%; R0603
R9: 3K3 1%; R0603
S1: PUSH_BUTTON; TLE1105
SB1: JUMPER_SOLDER_1X2
U1: LTC2943; DFN8-3X3
U2: FT232RL; SSOP28DB
U3: LT1764AEQ; TO263-5
U4: ATMEGA328TQFP32; TQFP32-08
U5: TC1015; SOT25
U$28: OSH

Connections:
+5V: C3.+, C4.1, C14.1, J1.1 (VBUS), U3.1 (SHDN), U3.2 (IN), U5.1 (VIN), U5.3 (SHDN)
DEBUG: U4.2 (PD4(XCK/T0))
GND: C1.2, C2.-, C3.-, C4.2, C5.2, C7.2, C8.-, C9.2, C10.2, C11.2, C12.2, C13.2, C14.2, J1.5 (GND), J2.5 (GND), J4.2, J5.6, OLED.1 (GND), R9.2, R11.1, S1.A (1), U1.2 (GND), U1.3 (GND), U1.7 (GND), U1.EXP (GND), U2.7 (GND), U2.18 (GND), U2.21 (GND), U2.25 (GND), U2.26 (TEST), U3.3 (GND), U3.6 (GND), U4.3 (GND), U4.5 (AGND), U4.21 (GND), U5.2 (GND)
I2C-CLK: R3.1, U1.4 (SCL), U4.28 (PC5(ADC5/SCL))
I2C-DATA: R2.1, U1.5 (SDA), U4.27 (PC4(ADC4/SDA))
MISO: J5.1, U4.16 (PB4(MISO))
MOSI: J5.4, OLED.4 (SDA), U4.15 (PB3(MOSI/OC2))
unnamed: R1.1, U1.6 (ALCC)
unnamed: C11.1, Q1.1, U4.7 (PB6(XTAL1/TOSC1))
unnamed: R4.2, U2.1 (TXO)
unnamed: C12.1, Q1.3 (2), U4.8 (PB7(XTAL2/TOSC2))
unnamed: R5.2, U2.5 (RXI)
unnamed: C8.+, C9.1, R6.I2, U3.4 (OUT)
unnamed: J2.3 (D+), U2.15 (D+)
unnamed: C6.1, U2.2 (DTRO)
unnamed: C6.2, SB1.1
unnamed: J2.2 (D-), U2.16 (D-)
unnamed: C7.1, U2.17 (3V3OUT)
unnamed: R7.1, R7.2, R9.1
unnamed: R7.3, R8.2, U3.5 (ADJ)
unnamed: J4.1, J4.3, R6.I1, R8.1
OLED_D/C: OLED.6 (D/C), U4.11 (PD7(AIN1))
OLED_RST: OLED.5 (RST), R11.2, U4.10 (PD6(AIN0))
RESET: J5.5, R10.1, SB1.2, U4.29 (PC6(/RESET))
SCK: J5.3, OLED.3 (SCL), U4.17 (PB5(SCK))
SENSE+: C1.1, R6.V2, U1.1 (SENSE+/VCC)
SENSE-: R6.V1, U1.8 (SENSE-)
SER_RX: R4.1, U4.30 (PD0(RXD))
SER_TX: R5.1, U4.31 (PD1(TXD))
START: S1.B (2), U4.32 (PD2(INT0))
VCC: C10.1, C13.1, J5.2, OLED.2 (VCC), R1.2, R2.2, R3.2, R10.2, U4.4 (VCC), U4.6 (VCC), U4.18 (AVCC), U5.5 (VOUT)
VUSB: C2.+, C5.1, J2.1 (VBUS), U2.4 (VCCIO), U2.20 (VCC)

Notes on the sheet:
USB/SERIAL (OPTIONAL)
ICSP (FOR POGO PINS)
MCU
POWER PLAY 3.8V
CURRENT SENSE
VOLTAGE REGULATOR
+5V
LOGIC ANALYZER (PROTOYPE ONLY)
USB
TO DEVICE
3.8V
* PROTOTYPE ONLY
"ARDUINO MINI PRO 328P 5V 16Mhz"
BUTTON
SOURCE
DISPLAY
Dev
VCC LDO (4V)
(3.6V-4.2V)

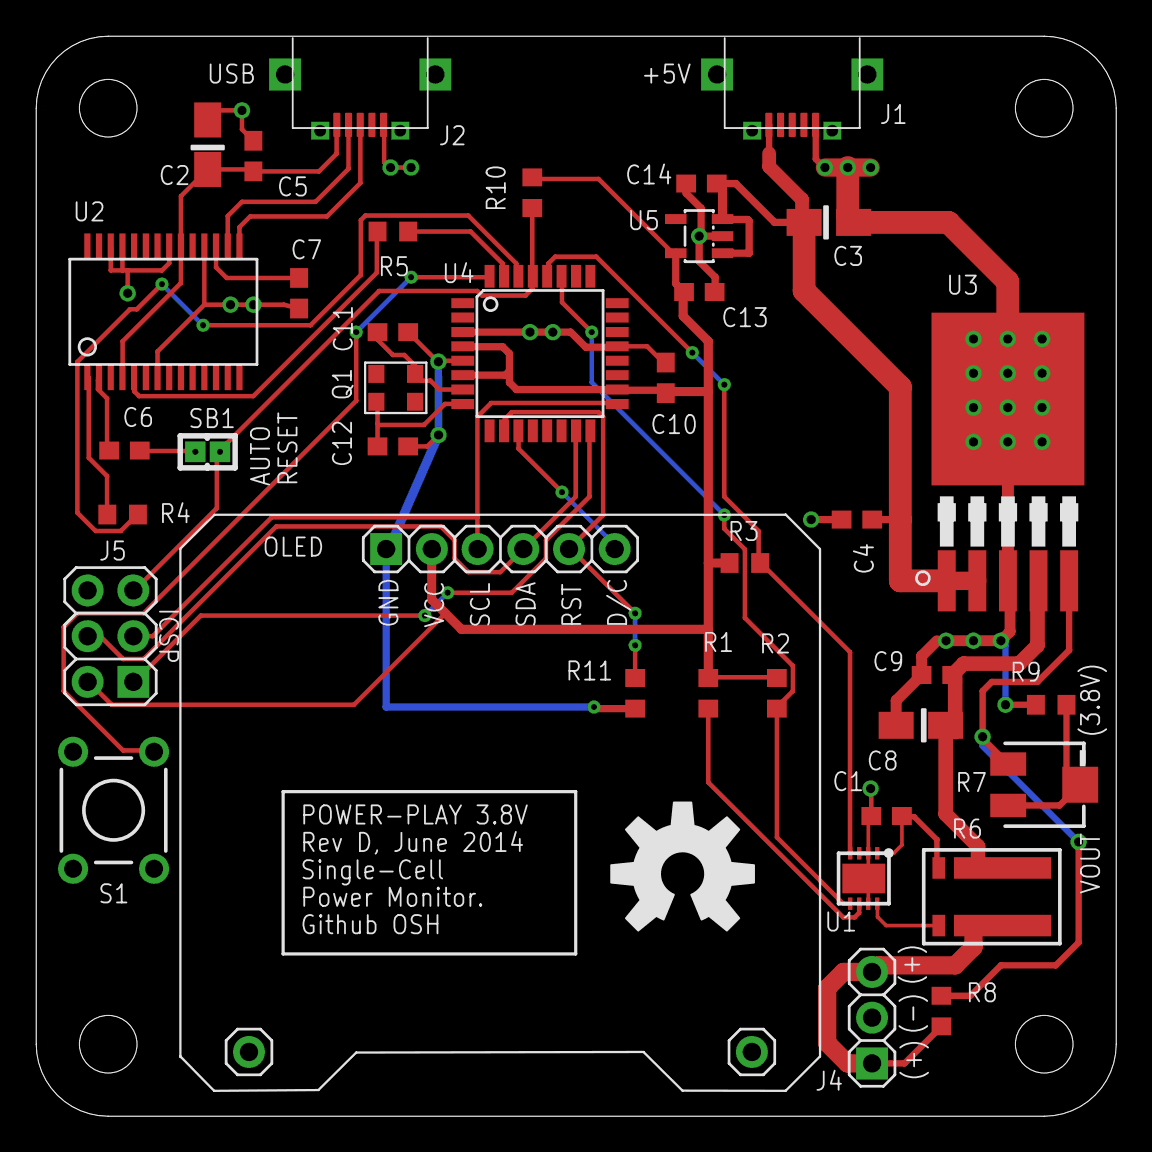
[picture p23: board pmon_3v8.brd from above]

Board: 2 copper layers, 60.0 x 60.0 mm, 39 parts (0 on the bottom side), 31 nets.

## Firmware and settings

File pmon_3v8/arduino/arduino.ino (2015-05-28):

// Licensed under the Apache License, Version 2.0 (the "License");
// you may not use this file except in compliance with the License.
// You may obtain a copy of the License at
//
//    http://www.apache.org/licenses/LICENSE-2.0
//
// Unless required by applicable law or agreed to in writing, software
// distributed under the License is distributed on an "AS IS" BASIS,
// WITHOUT WARRANTIES OR CONDITIONS OF ANY KIND, either express or implied.
// See the License for the specific language governing permissions and
// limitations under the License.

// NOTE: to examine the static RAM used by this program run 
// avr-size -C --mcu=atmega328p  <build_output_path>/arduino.cpp.elf

// If any of these checks fail, make sure you setup the Arduino IDE Board to
// Arduino Pro or Pro Mini (5V, 16Mhz) w/ Atmega 328P'.
#ifndef __AVR_ATmega328P__
#error "Unexpected MCU"
#endif
#if F_CPU != 16000000
#error "Unexpected CPU speed"
#endif

#include "analysis.h"
#include "avr_util.h"
#include "button.h"
#include "display.h"
#include "display_messages.h"
#include "ltc2943.h"
#include "passive_timer.h"
#include "U8glib.h"
#include "version.h"

namespace display_page {
  // Page ids.
  static const uint8 kGraphPage = 1;
  static const uint8 kSummary1Page = 2; 
  static const uint8 kSummary2Page = 3; 
 
  // Pages metadata
  static const uint8 kDefaultPage = kGraphPage;
  static const uint8 kMinPage = kGraphPage;
  static const uint8 kMaxPage = kSummary2Page;
}

// Current display page. One of display_page:: values.
// Not used when in test mode.
static uint8 selected_display_page;

// Indicates if the unit is in test mode (used for post manufacturing tests). The test
// mode is activated by pressing the button while turning the unit on. To exist the
// test mode power cycle the unit (without having the button pressed).
static boolean is_in_test_mode;

// Called from the main loop() when in test mode. It echos serial in to serial out.
// Testing serial in is important because it is used for firmware upgrade via the 
// serial bootloader.
static inline void test_mode_serial_echo_loop() {
  if (Serial.available()) {
    const unsigned char b = Serial.read();
    if ((b == '\n') || (b == '\r')) {
      printf(F("\n"), b);
    } else {
      printf(F("[%c]"),  b); 
    }   
  } 
}

// Not used when in test mode.
// Increment selected_display_page to the next page.
static inline void incrementCurrentDisplayPage() {
  // Assuming upon entry value is valid.
  if (++selected_display_page > display_page::kMaxPage) {
    selected_display_page = display_page::kMinPage;
  }
}

// Output pin for debugging.
io_pins::OutputPin debug_pin(PORTD, 4);

// 8 bit enum with main states.
namespace states {
  const uint8 INIT = 1;
  const uint8 REPORTING = 3;
  const uint8 ERROR = 4;
}
static uint8 state = 0;

// INIT state declaration.
class StateInit {
  public:
    static inline void enter();
    static inline void loop();  
};

// REPORTING state declaration.
class StateReporting {
  public:
    static inline void enter();
    static inline void loop();  
  private:
    // Before starting the first slot we first perform an initial reading
    // of the charge counter. This point in time is the 0 time mark of this analysis. 
    static bool has_last_reading;
       
    static uint32 last_slot_time_millis;
    static uint16 last_slot_charge_ticks_reading;
    
    // Used to track the various slots data.
    static analysis::SlotTracker slot_tracker;
};

bool StateReporting::has_last_reading;
uint32 StateReporting::last_slot_time_millis;
uint16 StateReporting::last_slot_charge_ticks_reading;  
analysis::SlotTracker StateReporting::slot_tracker;

// ERROR state declaration.
class StateError {
  public:
    static inline void enter(uint8_t displayMessageCode);
    static inline void loop(); 
  private:
    static PassiveTimer time_in_state; 
};
PassiveTimer StateError::time_in_state;

// Arduino setup function. Called once during initialization.
void setup() {;
  Serial.begin(115200);
  
  // NOTE: using compile time literal string concatenation.
  printf(F("\n# Ver " POWER_PLAY_VERSION_STRING "\n"));

  button::setup();
  
  // Wait until button debouncer stabilizes and check if pressed. This will
  // activate the test mode.
  //
  // TODO: skip the debouncer stabilization and just read the button pin once. This will
  // speedup the setup.
  while (!button::hasStableValue()) {
    button::loop();
  }
  is_in_test_mode = button::isButtonPressed();
  if (is_in_test_mode) {
    printf(F("# Test mode.\n"));
  }
  
  // Setup display.
  display::setup();
  selected_display_page = display_page::kDefaultPage;

  // Initialize the LTC2943 driver and I2C library.
  // TODO: move this to state machine, check error code.
  ltc2943::setup();
  
  StateInit::enter();
 
  // Enable global interrupts.
  sei(); 
  
  // Display startup message.
  const uint8 startup_message = is_in_test_mode 
      ? display_messages::code::kTestMode
      : display_messages::code::kSplashScreen;
  display::showMessage(startup_message, 1500);
}

void StateInit::enter() {
  state = states::INIT;
}

void StateInit::loop() {
  if (ltc2943::init()) {
    StateReporting::enter();
  } else {
    printf(F("# LTC2943 init failed (is power connected?)\n"));
    StateError::enter(display_messages::code::kLtc2943InitError);
  }
}

void StateReporting::enter() {
  state = states::REPORTING;
  has_last_reading = false;
}

void StateReporting::loop() {
  debug_pin.high();
  debug_pin.low();
  
  if (is_in_test_mode) {
    test_mode_serial_echo_loop();
  }
  
  // Handle button events. We ignore it if in test mode.
  if (!is_in_test_mode) {
    const uint8 button_event = button::consumeEvent();
    // Short click- TBD
    if (button_event == button::event::kClick) {
       incrementCurrentDisplayPage();
    }
    // Long press - reset the analysis
    else if (button_event == button::event::kLongPress) {
       printf(F("\n"));
       // Reenter the state. This also resets the accumulated charge and time.
       StateReporting::enter();
       display::showMessage(display_messages::code::kAnalysisReset, 750);
       return;  
    }
  }
  
  // If we don't have the first reading, read the charge tick register and initialize
  // the analysis.
  if (!has_last_reading) {
    if (!ltc2943::readAccumCharge(&last_slot_charge_ticks_reading)) {
      printf(F("# LTC2943 charge reading failed (1)\n"));
      StateError::enter(display_messages::code::kLtc2943InitError);
      return;
    }
    has_last_reading = true;
    last_slot_time_millis = millis();
    slot_tracker.ResetAll();
    
    display::clearGraphBuffer();
    return;
  }
  
  // Check if this time slot is over.
  // NOTE: the time check below should handle correctly 52 days wraparound of the uint32
  // time in millis.
  const int32 millis_in_current_slot = millis() - last_slot_time_millis;
  if (millis_in_current_slot < analysis::kMillisPerSlot) {
    return;
  }
  
  // NOTE: we keep the nominal reporting rate. Jitter in the reporting time will not 
  // create an accumulating errors in the reporting charge since we map the charge to
  // current using the nominal reporting rate as used by the consumers of this data.
  last_slot_time_millis += analysis::kMillisPerSlot;
  
  // Read and compute the charge ticks in this slot.
  uint16 this_slot_charge_ticks_reading;
  if (!ltc2943::readAccumCharge(&this_slot_charge_ticks_reading)) {
      printf(F("# LTC2943 charge reading failed (2)\n"));
      StateError::enter(display_messages::code::kGeneralError);
      return;
  }
  // NOTE: this should handle correctly charge register wraps around.
  const uint16 charge_ticks_in_this_slot = 
      (this_slot_charge_ticks_reading - last_slot_charge_ticks_reading);
  last_slot_charge_ticks_reading = this_slot_charge_ticks_reading;
  
  // Error if the current is reversed. 
  if (charge_ticks_in_this_slot >= 0x8000) {
    printf(F("# Reversed current\n"));
    StateError::enter(display_messages::code::kCheckReverseCurrentError);
    return;
  }
  
  // Update analysis with slot data.
  slot_tracker.AddSlot(charge_ticks_in_this_slot);

  // Read also the voltage
  uint16 voltage_raw_register_value;
  uint16 voltage_mv;
  if (!ltc2943::readVoltage(&voltage_raw_register_value, &voltage_mv)) {
    printf(F("# LTC2943 voltage reading failed\n"));
    StateError::enter(display_messages::code::kGeneralError);
    return;
  }
  const analysis::PrintableMilsValue printable_voltage(voltage_mv);
  
  // Compute last slot values.
  analysis::ChargeResults last_slot_charge_results;
  analysis::ComputeChargeResults(slot_tracker.last_slot_charge_tracker, &last_slot_charge_results);
  analysis::PrintablePpmValue last_slot_amps_printable(last_slot_charge_results.average_current_micro_amps);
  const uint16 last_slot_current_millis = last_slot_charge_results.average_current_micro_amps / 1000;
  
  // Compute super slot values.
  analysis::ChargeResults prev_super_slot_charge_results;
  analysis::ComputeChargeResults(slot_tracker.prev_super_slot_charge_tracker, &prev_super_slot_charge_results);
  //analysis::PrintablePpmValue prev_super_slot_amps_printable(prev_super_slot_charge_results.average_current_micro_amps);
  
  analysis::ChargeResults prev_super_slot_total_charge_results;
  analysis::ComputeChargeResults(slot_tracker.total_charge_tracker_at_prev_super_slot, &prev_super_slot_total_charge_results); 
  
  // Compute total values in this analyais. 
  analysis::ChargeResults total_charge_results;
  analysis::ComputeChargeResults(slot_tracker.total_charge_tracker, &total_charge_results); 
  analysis::PrintablePpmValue total_charge_amp_hour_printable(total_charge_results.charge_micro_amps_hour);
  analysis::PrintablePpmValue total_average_current_amps_printable(total_charge_results.average_current_micro_amps); 

  analysis::PrintableMilsValue timestamp_secs_printable(slot_tracker.total_charge_tracker.time_millis);
  
  analysis::ChargeResults wake_slots_charge_results;
  analysis::ComputeChargeResults(slot_tracker.wake_slots_charge_tracker, &wake_slots_charge_results);
  
  // Append the last slot current to the display graph buffer.
  display::appendGraphPoint(last_slot_current_millis);
  
  // Render the current display page.
  if (is_in_test_mode) {
    display::renderTestPage(printable_voltage, last_slot_amps_printable, 
        this_slot_charge_ticks_reading, button::isButtonPressed());
  } else if (selected_display_page == display_page::kGraphPage) {
    display::renderGraphPage(prev_super_slot_charge_results.average_current_micro_amps, 
        prev_super_slot_total_charge_results.average_current_micro_amps);
  } else if (selected_display_page == display_page::kSummary1Page) {
    //const uint16 current_millis = major_slot_charge_results.average_current_micro_amps / 1000;
    const uint16 total_charge_milli_amp_hour = total_charge_results.charge_micro_amps_hour / 1000;
    display::renderSummary1Page(
        prev_super_slot_charge_results.average_current_micro_amps, 
        prev_super_slot_total_charge_results.average_current_micro_amps, 
        total_charge_milli_amp_hour, timestamp_secs_printable.units);     
  } else if (selected_display_page == display_page::kSummary2Page) {
    display::renderSummary2Page(
        printable_voltage, 
        slot_tracker.last_slot_was_wake,
        slot_tracker.total_wakes,
        wake_slots_charge_results.charge_micro_amps_hour / 1000,
        timestamp_secs_printable.units);        
  } else {
    display::showMessage(display_messages::code::kGeneralError, 100);
  }
  
  // In test mode we echo serial in to serial out so supressing these printouts
  // to reduce clutter on serial out.
  if (!is_in_test_mode) {
    // NOTE: we split the formatting so we don't hit the limit of the static buffer of
    // avr_util.h/printf(). 
    printf(F("%u.%03u %u.%03u %u.%03u %u.%03u"), 
        timestamp_secs_printable.units,  timestamp_secs_printable.mils, 
        last_slot_amps_printable.units, last_slot_amps_printable.mils, 
        total_charge_amp_hour_printable.units, total_charge_amp_hour_printable.mils,
        total_average_current_amps_printable.units, total_average_current_amps_printable.mils); 
    printf(F(" %lu %lu %lu %u\n"), 
        slot_tracker.standby_slots_charge_tracker.time_millis,
        slot_tracker.wake_slots_charge_tracker.time_millis,
        slot_tracker.total_wakes,
        (slot_tracker.last_slot_was_wake ? 1 : 0)); 
  }
}

inline void StateError::enter(uint8 displayMessageCode) {
  state = states::ERROR;
  time_in_state.restart(); 
  // NOTE: to trigger this error for testing, short the 8.2k resistor between the 
  // device (+) output and the voltage adjustment potentiometer. 
  // This will reduce the output voltage to ~1.5V and will make the LTC2942 non responsive. 
  // Or, with the 5V or 20V versions, feed the power through the output to generate a reversed
  // current.
  display::showMessage(displayMessageCode, 1500);
}

inline void StateError::loop() {
  // Insert a short delay to avoid flooding the serial output with error messages
  // in case we have a permanent error condition.
  if (time_in_state.timeMillis() < 1000) {
    return;
  }
  // Try again from scratch.
  StateInit::enter();
}

// Arduino loop() method. Called after setup(). Never returns.
// This is a quick loop that does not use delay() or other 'long' busy loops
// or blocking calls. typical iteration is ~ 50usec with 16Mhz CPU.
void loop() {
  // Call the loop() function of the underlying modules.
  button::loop();
  
  switch (state) {
    case states::INIT:
      StateInit::loop();
      break;
    case states::REPORTING:
      StateReporting::loop();
      break;
    case states::ERROR:
      StateError::loop();
      break;
    default:
      printf(F("# Unknown state: %d\n"), state);
      StateError::enter(display_messages::code::kGeneralError);
      break;  
  }
}

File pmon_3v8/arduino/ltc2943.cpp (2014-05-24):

// Licensed under the Apache License, Version 2.0 (the "License");
// you may not use this file except in compliance with the License.
// You may obtain a copy of the License at
//
//    http://www.apache.org/licenses/LICENSE-2.0
//
// Unless required by applicable law or agreed to in writing, software
// distributed under the License is distributed on an "AS IS" BASIS,
// WITHOUT WARRANTIES OR CONDITIONS OF ANY KIND, either express or implied.
// See the License for the specific language governing permissions and
// limitations under the License.

#include "ltc2943.h"

#include "i2c.h"

namespace ltc2943 {
  
// The fixed address of all TLC2943 IC's. Per the datasheet, it is hard coded and 
// cannot be configured.
static const uint8 kLtc2943BaseAddress = 0x64;

// LTC2943 8 byte registers.
namespace regs8 {
  const uint8 kStatus = 0x00;
  const uint8 kControl = 0x01;
}

// LTC2943 16 byte registers.
namespace regs16 {
  const uint8 kAccumCharge = 0x02;
  const uint8 kVoltage = 0x08;
  const uint8 kCurrent = 0x0e;
  const uint8 ktemperature = 0x14;
}

// Control register fields.
static const uint8 kLtc2943AutomaticMode  = 0xc0;
static const uint8 kLtc2943PrescalarX1    = 0x00;
static const uint8 kLtc2943DisableAlccPin = 0x00;

// I2C start or repeated start for the LTC2943 read.
static inline bool startI2CRead() {
  return i2c::start((kLtc2943BaseAddress << 1) | i2c::direction::READ)  ;
}

// I2C start or repeated start for the LTC2943 write.
// Returns true if ok.
static inline bool startI2CWrite() {
  return i2c::start((kLtc2943BaseAddress << 1) | i2c::direction::WRITE)  ;
}

// Write a value to a LTC2943 8 bit register. Returns true if ok.
static bool writeReg8(uint8 reg,  uint8 value) {
  // Using boolean short circuit.
  const bool is_ok = startI2CWrite()    
      && i2c::writeByte(reg)                      
      && i2c::writeByte(value);                     
  i2c::stop(); 
  return is_ok; 
}

// Write a value to a LTC2943 16 bit register (a pair of two 8 bit registers, MSB first). 
// Returns true if ok.
static bool writeReg16(uint8 base_reg,  uint16 value) {
  // Using boolean short circuit.
  const bool is_ok = startI2CWrite()
      && i2c::writeByte(base_reg)                      
      && i2c::writeByte(highByte(value))  
      && i2c::writeByte(lowByte(value));                       
  i2c::stop(); 
  return is_ok;  
}

// Read a LTC2943 8 bit register. Returns true if ok.
static bool readReg8(uint8 reg, uint8* value) {
  // Using boolean short circuit.
  const bool is_ok = startI2CWrite()
      && i2c::writeByte(reg)  
      && startI2CRead()
      && i2c::readByteWithNak(value);
  i2c::stop();
  return is_ok;
}

// Read a LTC2943 16 bit register (a pair of two 8 bit registers, MSB first). 
// Returns true if ok.
static bool readReg16(uint8 reg, uint16* value) {
  uint8 msb;
  uint8 lsb;
  
  // Using boolean short circuit.
  const bool is_ok =  startI2CWrite()  
      && i2c::writeByte(reg)  
      && startI2CRead()
      && i2c::readByteWithAck(&msb)
      && i2c::readByteWithNak(&lsb);
  i2c::stop();
  
  // TODO: write directly to the msb, lsb bytes of value.
  // For now, in case of an error, we return undefined value.
  if (is_ok) {
    *value = word(msb, lsb);
  }
  
  return is_ok;
}

void setup() {
  i2c::setup();
}

// Returns true if ok.
bool init() {
  const uint8 control_mode = kLtc2943AutomaticMode | kLtc2943PrescalarX1 | kLtc2943DisableAlccPin ;              
  return writeReg8(regs8::kControl, control_mode);
}

// Return true if ok.
boolean readAccumCharge(uint16* value) {
  return readReg16(regs16::kAccumCharge, value);
}

// Return true if ok.
boolean readVoltage(uint16* raw_register_value, uint16* voltage_mv) {
  if (!readReg16(regs16::kVoltage, raw_register_value)) {
    return false;
  }
  // NOTE: using a top value of 0x10000 instead of 0xffff as specified in the datasheet.
  // The affect on the accuracy is insignificant.  Adding the 0x8000 to round to the closest
  // mv.
  *voltage_mv = ((((uint32)23600) * (*raw_register_value)) + 0x8000) >> 16;
  return true;
}
  
}  // namespace ltc2943

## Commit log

2014-04-19 Moved files from the temporary repository.
    [powermon.brd, powermon.sch]
2014-04-19 Renamed eagle files from powermon.* t pmon_uno.*
    [pmon_uno.brd, pmon_uno.sch]
2014-04-19 Replaced dipswitch to through hole. Undone auto routing.
    [pmon_uno.brd, pmon_uno.sch]
2014-04-19 Changed board fonts to vector, tweaked text. No final auto routing yet.
    [pmon_uno.brd]
2014-04-20 Rearanged the leds pin to have a PWM option for the Status led.
    [pmon_uno.brd, pmon_uno.sch]
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2014-04-20 Added outline of a basic cover.
    [cover_top.brd, cover_top.dxf]
2014-04-20 Changed the button and power terminals to be top access (incremented to Rev B), Yet to be auto routed.
    [cover_top.brd, cover_top.dxf, pmon_uno.brd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]
2014-04-21 Rev B is fully routed.
    [pmon_uno.brd, pmon_uno.sch]
2014-04-21 Minor board tweak, adjusted via size.
    [pmon_uno.brd]
2014-04-21 Changed the via stop limit from 20 to 30mils.
    [pmon_uno.brd]
2014-04-21 Added laser cutting design for top and bottom covers.
    [cover_bottom.brd]
2014-04-22 Handled truncation errors. Need to revisit.
    [arduino.ino]
2014-04-23 Started to cleanup the pmon uno BOM.
    [pmon_uno.brd, pmon_uno.sch]
2014-04-23 Simplified the computations. Fixed the truncation errors.
    [arduino.ino]
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2014-04-25 Minor Eagle tweaks: 1. Added a debug pin to the logic analyzer signals. 2. Changed the top and bottom drill sizes from 2.5mm to 3mm.
    [cover_bottom.brd, cover_top.brd, pmon_uno.brd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]
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2014-05-03 Minor text tweaks. No semantic change.
    [pmon_uno.brd, pmon_uno.sch]
2014-05-08 Updated schematic and board for rev c.
    [pmon_uno.brd, pmon_uno.sch]
2014-05-08 Increased the dril of the USB connector two main support tabs.
    [pmon_uno.brd, pmon_uno.sch]
2014-05-08 Respaced the LED row.
    [pmon_uno.brd]
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2014-05-08 Added to top cover a cut for the power selector jumpers.
    [cover_top.brd]
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2014-05-10 Changed resistor values to reduce part SKU count. Selected different 1% resistor since the old ones did not have readable markings.
    [pmon_uno.brd, pmon_uno.sch]
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2014-05-15 First checkin of the pmon OLED. This is a fork of the pmon UNO.
    [pmon_oled.sch]
2014-05-15 Added detection of button click and long press. Long press currently resets the analysis. Click will switch display pages in a later commit.
    [arduino.ino]
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2014-05-16 Added display messages. Still need to implement the rest (e.g. LTC2943 error message).
    [arduino.ino]
2014-05-16 Checkin in pending changes.
    [pmon_oled.sch]
2014-05-17 Removed the errors led. Error message is now shown on the display.
    [arduino.ino]
2014-05-21 Routed critical networks. Ready for final auto routing.
    [pmon_oled.brd, pmon_oled.sch]
2014-05-21 Minor board tweaks. Ready for final auto routing.
    [pmon_oled.brd]
2014-05-21 Updated the layout for physical clearance.
    [pmon_oled.brd, pmon_oled.sch]
2014-05-21 Tweaks criticla nets to improve auto rounting. Should be ready for final auto routing.
    [pmon_oled.brd]
2014-05-21 Moved the bstop layer text up to the copper area.
    [pmon_uno.brd]
2014-05-21 Beefed up a few power traces.
    [pmon_oled.brd]
2014-05-21 Perfomed auto routing of non critical nets.
    [pmon_oled.brd]
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2014-05-26 Changed reset capacitor from 0.01 to 0.1 (to reduce compoent kind count).
    [pmon_oled.brd, pmon_oled.sch, pmon_uno.brd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]
2014-05-27 Removed the concept of major vs minor slots. Now having only one kind. Changing reporting mode does not reset analysis anymore.
    [arduino.ino]
2014-05-27 Upshing pending oled changes.
    [cover_bottom.brd, cover_top.brd]
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2014-05-28 Redesigned the OLED board to pass 5V through rather than regulating to 3.8. This way it can be sued with non instrumeted devices, feeding to the USB input (with some reduce accuracy due to charger st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
    [cover_top.brd, pmon_oled.brd, pmon_oled.sch]
2014-05-29 Restoring the pmon_oled design with 3.8V regulator.
    [cover_top.brd, pmon_oled.brd, pmon_oled.sch]
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2014-05-30 Removed the config dip switches.
    [cover_top.brd, pmon_oled.brd, pmon_oled.sch]
2014-05-30 Updated library (larger header pads) and auto rerouted.
    [pmon_oled.brd, pmon_oled.sch]
2014-06-03 Added a 5V pass through version of pmon oled.
    [pmon_5v.brd, pmon_5v.sch]
2014-06-03 Added pdf dumps of board and schematic.
    [pmon_5v.sch]
2014-06-03 Performed the final auto routing.
    [pmon_5v.brd]
2014-06-04 Cleaned up the board.
    [pmon_5v.brd, pmon_5v.sch]
2014-06-04 Tweaked usb A support pads.
    [pmon_5v.brd, pmon_5v.sch]
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2014-06-04 Made the dimension outline to have non zero width so it is shown in all gerber viewers.
    [pmon_oled.brd]
2014-06-05 Removed power led, added vias to the solder jumpers.
    [pmon_5v.brd, pmon_5v.sch, pmon_oled.brd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]
2014-06-06 Removed PMpn UNO. Obsolete.
    [cover_bottom.brd, cover_top.brd, pmon_uno.brd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]
2014-06-06 Added pmon_5v BOM. Minor tweaks of schematics and layouts.
    [pmon_5v.sch, pmon_oled.brd, pmon_oled.sch]
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2014-06-12 Missing change from previous commiet.
    [arduino.ino]
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2014-06-21 Updated the LTC2943 footpting to match the datasheet (longer pads now).
    [pmon_5v.brd, pmon_5v.sch, pmon_oled.brd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]
2014-06-21 Renamed power play oled to power play 3.8V (to be consistent with the 5V name of the other variant).
    [cover_bottom.brd, cover_top.brd, pmon_3v8.brd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]
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2014-06-25 Added OLED reset pull down resistor.
    [pmon_3v8.brd, pmon_3v8.sch]
2014-06-25 Added OLED reset pulldown resistor.
    [pmon_5v.brd, pmon_5v.sch]
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2014-06-30 Added 4V regulator. Yet to do final auto routing.
    [pmon_3v8.brd, pmon_3v8.sch, pmon_5v.brd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]
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2014-06-30 Updated laser cut design files.
    [cover_bottom.brd, cover_top.brd]
2014-07-01 Increased the paste area of the LTC2943.
    [pmon_3v8.brd, pmon_3v8.sch, pmon_5v.brd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]
2014-07-10 ATMEGA328P breakout board. Ready for final auto routing.
    [atmega328_breakout.brd, atmega328_breakout.sch]
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2014-07-10 Fixed dimension to copper clearance.
    [atmega328_breakout.brd, atmega328_breakout.sch]
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2014-07-13 Renamed +4V network to VCC. No semantic change.
    [pmon_3v8.brd, pmon_3v8.sch, pmon_5v.brd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]
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2014-07-22 Added FT232RL breakout. Ready for final auto routing.
    [atmega328_breakout.brd, ft232rl_breakout.brd, ft232rl_breakout.sch]
2014-07-22 Updated the placement. Ready for final auto router.
    [ft232rl_breakout.brd]
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2014-07-23 Added a laser cut bracket for PCB stenciling.
    [pcb_bracket_small.brd]
2014-07-27 Minor layout change. Reroute a short between two pins to avoid reflow that looks like a solder bridge.
    [pmon_3v8.brd, pmon_5v.brd]
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2014-08-01 Added tcream holes for usb connector tabs. Added bom.
    [ft232rl_breakout.brd, ft232rl_breakout.sch]
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2014-09-07 Formated screen to display correctly voltages above 9.999V.
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2015-01-08 Minor BOM fixes.
    [pmon_5v_bom.csv]
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2015-05-14 Added pmon 20V max. Yet to do final routing.
    [pmon_20v.brd, pmon_20v.sch, pmon_20v_bom.csv]
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2015-05-28 Now detecting reversed current. Also, fixed voltage display overflow for 10+ voltes.
    [arduino.ino]
